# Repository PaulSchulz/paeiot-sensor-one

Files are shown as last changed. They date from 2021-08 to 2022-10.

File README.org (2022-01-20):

* paeiot-sensor-one :TOC:
  - [[#introduction][Introduction]]
  - [[#aim][Aim]]
  - [[#whats-in-this-repository][What's in this Repository]]
  - [[#usage-license][Usage License]]

** Introduction
PAE IoT LoRaWAN Sensor Module

This project is a product of the [[https://github.com/PaulSchulz/paeiot-experimenters][Port Adelaide Enfield Libraries IoT Experimenters]]
group.

The latest details for this project can be found in the regular [[blog/index.org][status updates]].
Comments are most welcome. See the above link for the group details.

#+CAPTION: Sensor One in a 3D Printed Indoor Enclosure
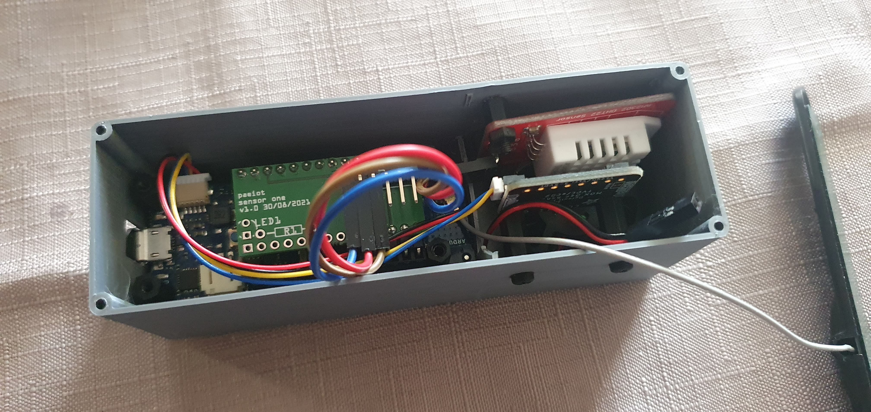
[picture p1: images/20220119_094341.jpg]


#+CAPTION: Outdoors Temperature and Humidity Sensor
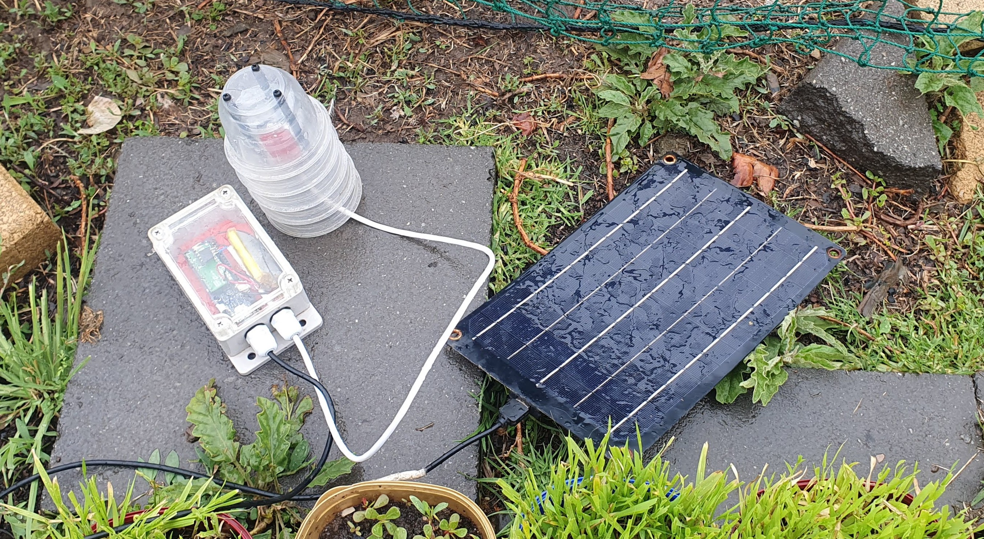
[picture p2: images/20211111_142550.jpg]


#+CAPTION: Data from Sensor One Outdoors Temperature and Humidity Sensor
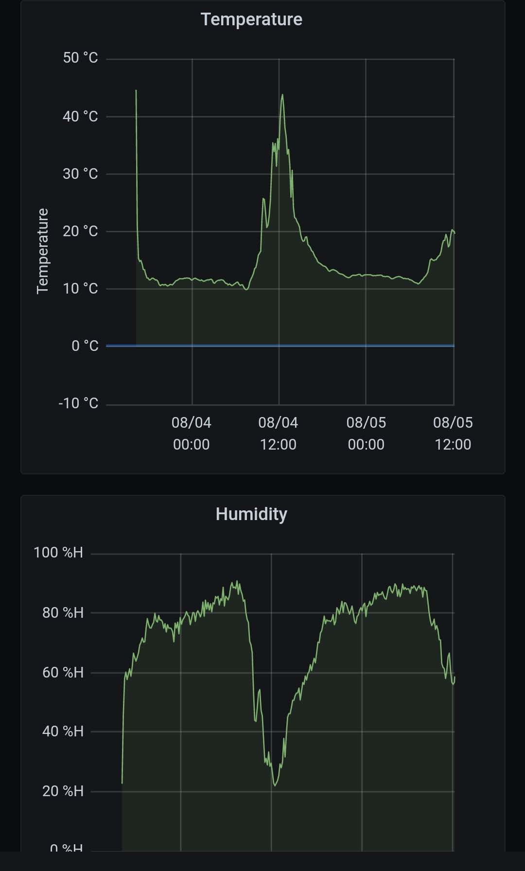
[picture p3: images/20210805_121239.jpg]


** Aim
Design and Build IoT LoRaWAN capable device which can be used for
environmental sensing.

The initial discussion paper (RFC) can be found here: [[https://github.com/PaulSchulz/paeiot-experimenters/blob/main/doc/rfc/00001-iot-lorawan-device.org][00001-iot-lorawan-device.org]]

The current project is based around the [[https://store.arduino.cc/usa/mkr-wan-1310][Arduino MRKWAN1310 board]], which uses a
SAND21 processor capable of low power operation, and a LoRa radio which allows
data logging via the LoRaWAN network.

** What's in this Repository
Subdirectories:
- [[Arduino/][Arduino]] - Directory containing Arduino sketches used by the project.
- [[doc/index.org][doc]] - Design and development documentation
- [[blog/index.org][blog]] - Progress Reports and Updates
- [[images/][images]]- Pictures, diagrams etc.
- [[stl/][stl]] - Sources for 3D printed parts
- [[fritzing/][fritzing]] - Sources for the Wiring Diagram, Printed Circuit Board (PCB) layout
  and production details, using the Friting application (old).
- [[kicad/][KiCAD]] - Sources for Wiring Diagram, Printed Circuit Board (PCB) layout
  and production details, using the KiCAD.

** Usage License

Unless mentioned elseware and where appropriate, all sources are made available
under a Free and Open Source License (GPLv3) for use for any purpose provided
that all derived works are made available under a Free and Open Source License.

See [[LICENSE]] for details.

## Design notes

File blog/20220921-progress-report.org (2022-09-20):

[[../README.org][Top]] | [[index.org][Index]]
-----

Microclimates - From the Coast to the Foothills (September Progress Report)

* Introduction

The Microclimates (Citizen Science) Project is flying ahead. Three sensors have
now been installed; located at the Port Adelaide Enfield Libraries at
Greenacres, Enfield and Port Adelaide. Two more sites are planned.

One big change with the firmware was required but otherwise, the sensors have
been deployed as designed.

The location has also been added to the data that is being collected, and the
graphs have been simplified and modified to allow additional sensors to
be automatically available.

A map has also been added which automatically shows the location of the
collected data.

[[https://grafana.iotdemo.dsp.id.au/d/ZxgEXUkVk/sensors-location-map?orgId=1&refresh=1m][Sensor Map]]

* Installation

** Greenacres (greenacres, mc-8)

This was the first site to be deployed and was reasonably straight forward.

It has been found that the sensor needs a LoRaWAN Gateway nearby to initially
connect to the network correctly. It is suspected that this is due to the
initial encryption handshake requires the sensor to also get a signal back from
a gateway. Once this has been done though, the sensor will happily transmit, and
gateways are able to pick up the signal without additional problems.

This issue also affects the sensor used for coverage mapping when starting up.
This can be addressed is a change to the firmware, where the LoRaWAN connection
can be tried again if it fails, after a timeout period.

** Enfield (enfield, mc-5)

The Enfield Libray sensor is located with the "Bee Hotel" and uses power from
the solar and battery system installed here. This means that the sensor is not reporting
it's solar and power levels (voltages) as the other sites are doing.

** Port Adelaide (port, mc-7)

Installation at this site required some 'finesse' in order to attach the sensor
to the outside of the library entrance, but it started recording data on Monday,
19 September ("port"", with sensor "mc-7").

** Next Sites (semaphore, park)

Work in ongoing to install sensors at Semaphore and The Parks Libraries

* Changes to the Firmware - Lowering Power Usage

Problems were found with excessive power usage on the processor. The delay
between measurements was beeing imposed by a 'busy sleep loop', which just kept
the processor running while waiting for the time for the next measurement.

This has ment that the sensor would use up all the battery power overnight, a
particular problem if the weather was overcast for a couple of days.

The solution was to use the low power sleep mode availble in the 'Sleepy Dog'
Arduino library. This reduced the power usage by a significant amount, to the
point where the power problem has essentially been solved. Measurements on
another sensor are ongoing to measure these results.

* Data Collection and Reporting

Updates have been made to the NodeRed data processing which now adds the
location (both site name and latitude and longitude)  to the data as it is collected. 

There are a couple of quick benefits from this. Site data can be consistently
displayed, even if a particular sensor fails and needs to be swapped out. Also,
the collected data can be displayed on a map with details about the site and
sensor at that location.

* Results

Grafana Graphs: [[https://grafana.iotdemo.dsp.id.au/d/BVf31-GVk/locations-all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][Dashboard]]

The initial data collected has already shown some interesting features, trends
and differences:
- The temperature and humidity data for each site generally track each other
  quite closely, generally within a degree or so, and 2% respectfully.
- There are still some interesting variabilities between the sensors, which are
  begging an explanation.
- It appears to be possible to detect the movement of a weather front through
  the Port Adelaide Enfield area by the delay in the temperature graphs.

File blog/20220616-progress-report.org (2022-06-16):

[[../README.org][Top]] | [[index.org][Index]]
-----

* Microclimates - From the Coast to the Foothills



Experimental setup of solar powered climate sensor stack. From the top - USB
solar panel; air temperature and humidity sensor in weather shield;
weather-proof box containing microprocessor board with LoRaWAN radio and
antenna.

** Progress Report - Thursday, 16 June 2022

Welcome to this (somewhat infrequent) update for the Sensor One IoT
project.

We have some big news.

Robert has been successful in obtaining a grant from National Science Week 2022
SA Community Grant for a microclimate measuring project in Port Adelaide Enfield
council - *From the coast to the foothills*

The sensors for the project will make use of the PAE IoT Experimenter's Group
Sensor One. While this is exciting, what is even better news is that we want to
use this opportunity to make the kit, with emphasis on a complete outdoor
environmental sensor package. The time frame for this is limited (about 4 months
in total), so the IoT Experimenter group is looking for people who may be able
to help out in many different ways.

The initial project kickoff meeting is being held during our regular meetup,
this Sunday, 19th June 2022, at 3pm at the Greenacres Library.

Some of the additional hardware features that can be looked at, in no
particular order:
- Adding a magnetic reset switch + circuit, for external sensor reset;
- Power usage measurement, and enabling microprocessor sleep modes;
- Add a watchdog circuit and automatic reset;
- Add power monitoring circuit (battery and power in); and
- Creating a version 2 of sensor circuit board.

Other useful activities:
- Robustness testing of sensors;
- Data modeling and analysis;
- Review of our IoT stack - The Things Network, NodeRED, InfluxDB and Grafana;
- NodeRED Flow Implementation;
- Grafana Dashboard Design;
- Documentation of hardware (bill of materials and build instructions), and
  project (blog and progress reports), including photography; and
- Design and preparation of 3D printed parts (if any).

*** More Information
- The project: https://stemlibrary.space/microclimates/
- An overview of the IoT: https://stemlibrary.space/iot-microclimate/
- An overview of the sensors we will be developing and deploying:
  https://stemlibrary.space/microclimate-sensor/

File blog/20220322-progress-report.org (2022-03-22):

[[../README.org][Top]] | [[index.org][Index]]
-----
* Progress Report - Saturday, 30 September 2022                          :TOC:
- [[#introduction--summary][Introduction / Summary]]
- [[#progress][Progress]]
  - [[#comments-on-coding-with-arduino-ides][Comments on Coding with Arduino IDEs]]
  - [[#investigating-the-cjmcu-8128-sensor-board][Investigating the CJMCU-8128 Sensor Board]]
  - [[#programming][Programming]]

* Introduction / Summary

|--------------+-------------------+---------+------------------------------------------------|
| Device       | Location / Role   | Status  | Comment                                        |
|--------------+-------------------+---------+------------------------------------------------|
| sally        | super-chook-house | WORKING | Stopped working due to faulty battery          |
| sensor-one-1 | lab               | TESTING |                                                |
| sensor-one-2 | kitchen           | WORKING | Was used to diagnose issues with other sensors |
| sensor-one-3 | bees              | BROKEN  | Broken and requires maintenance                |
| sensor-one-4 | lab / tracker     | BROKEN  | Requires software update to improve operation  |
|--------------+-------------------+---------+------------------------------------------------|

A quick update for March. Almost all of the sensors stopped working in one way or
another during this last period.

* Progress 
** Comments on Coding with Arduino IDEs
The following comments relate to using the various Arduino IDE's on Ubuntu 21.10. 

*** Arduino IDE v2

I decided to give the new (beta) Arduino development environment a go. It was a
very frustration experienced. It promises a lot with a new look and feel and
better library management, but it fell down with the management of the USB
programming and serial interface.

It would regularly, and without any obvious cause, stop being able to access the
device. Auto detection appeared to work well, but it than would not correctly
connect, or be able to program again after the Arduino MKR board was reset.

*** Arduino Cloud IDE

The Arduino Cloud IDE (browser based) works very well. An agent program needs to
be downloaded and run to allow it to access the USB ports for programming and
serial monitoring.

The library management is even extensive as all available online libraries are
available directly from within the tool. 

Compiling is done in the cloud, and the result is then downloaded to the
attached Arduino device, which was detected automatically.

The biggest issue I found was that there is a limit on the amount of compile
time is available (200 sec per day) under the free account level. It didn't take
very long to hit this limit.

*** Arduino IDE v1

I downloaded and updated to the latest version of the original Arduino IDE, and
was pleasantly surprised at how well it still worked.

The separate serial monitor can be made as big as required, and works well. 

While it isn't Emacs, it was still the easiest way to develop software for the
Sensor-One project.

** Investigating the CJMCU-8128 Sensor Board

This board is an I2C sensor board which combines three sensor chips. 

There was some confusion when wiring up the board, which was originally
connected directly to the I2C socket on the MKR board, which provides 5V rather
then 3.3V. This may have damaged the sensors, and the MKR board did not actually
boot in this configuration.

Correctly connecting the sensor to the 3.3V supply allowed the sensor to be read correctly. 

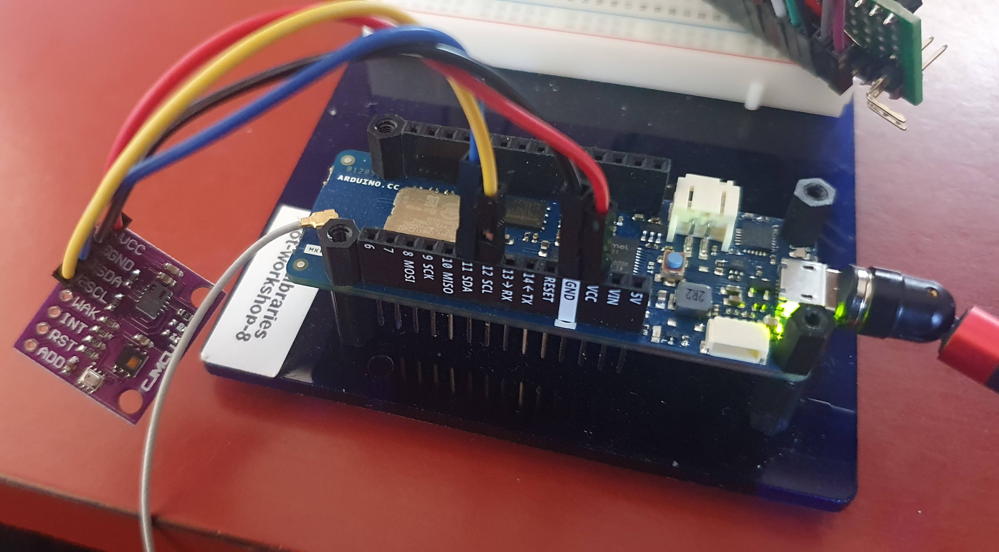
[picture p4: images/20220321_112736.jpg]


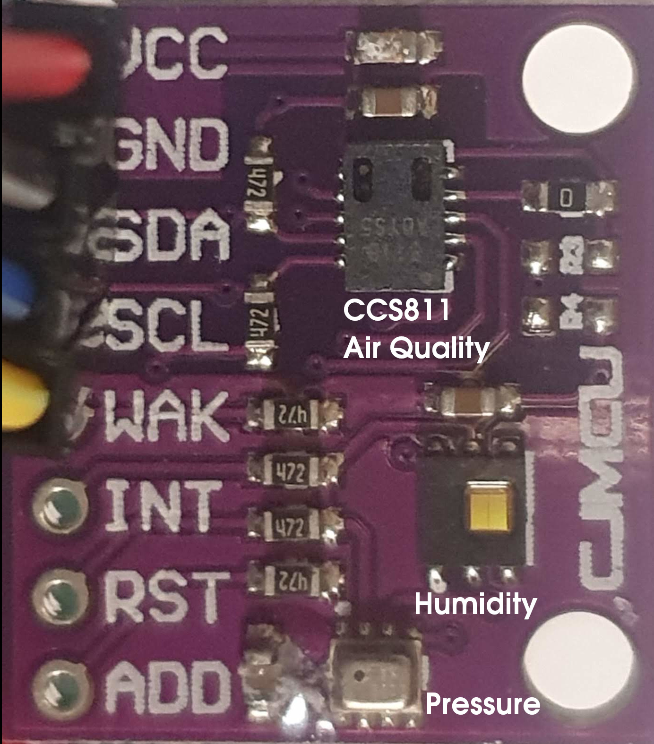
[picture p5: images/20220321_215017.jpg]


*** BME280 - Humidity sensor - Bosch
Datasheet: https://www.bosch-sensortec.com/products/environmental-sensors/humidity-sensors-bme280/

*** CCS811 - Air Quality Sensor - AMS
  Low Power Digital Gas Sensor. Datasheet: https://core-electronics.com.au/attachments/localcontent/CCS811_Datasheet-DS000459_65985a5bff8.pdf

*** HDC1080 - High Accuracy Humidity Sensor - Texas Instruments
Datasheet: https://www.ti.com/lit/ds/symlink/hdc1080.pdf

** Programming

Some more changes have been made to the 'Sensor One' code. Currently, the code
for the new sensors is still a work in progress, but several structural changes
have also been made.

The sensors connected to the MKR board can be chosen at compile time, and are
displayed when the software is run. This allows a working configuration (eg. for
the DHT sensors) to be put to the side while new code is developed.

#+begin_src 
# ----------------------------------------------------------------------------
# --- Sensor One                                                           ---
# --- Version: v1.3.0  21 Mar 2022                                         ---
# --- PAE IoT Experimenters                                                ---
# --- https://stemlibrary.space/iot-experimenters                          ---
# ----------------------------------------------------------------------------
# Features
#   LoRaWAN
#   CCS811
#   BME280
#   HDC1080
#   CayenneLPP
# ----------------------------------------------------------------------------
#+end_src

and is selected in the code with

#+begin_src 
// Features
#define LORAWAN            1
#define SENSOR_DHT         0
#define SENSOR_CCS811      1
#define SENSOR_BME280      1
#define SENSOR_HDC1080     1
#define FEATURE_CAYENNELPP 1
#+end_src

-----

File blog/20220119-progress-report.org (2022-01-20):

[[../README.org][Top]] | [[index.org][Index]]
-----
* Progress Report - Wednesday, 19 January 2022                            :TOC:
- [[#summary][Summary]]
- [[#update-details][Update Details]]

* Summary

This is a quick update, rather than a full progress report, on some recent work
on the Sensor One. This is because I am a little excited to show off what has
been recently done.

I was thinking about taking the sensor a little further and seeing how easily it
could be made into an indoor unit. 

There has been some announcements about delaying when Schools are going to start
again this year, because of COVID-19. A friend, who is a principal at a Primary
School in South Australia, ran a project last year using a CO2 sensor to monitor
air quality, so the students could tell when more fresh air and ventilation was
required. Their project has been [[https://www.facebook.com/LobethalLutheranSchool/videos/296081939214976][featured on the ABC]] and a video of their
work is available here: [[https://youtu.be/g7XMByInVQ0][YouTube Video]].

The PAE IoT - Sensor One, Air Quality Sensor in able do the same things as the
Primary School's sensor as it uses the same sensor device. With the addition of
a Raspberry Pi Computer, connected to your network and running free and open
source software, you can also [[file:../images/sensor-one-2-20220111.png][see the data]] in real time using the LoRaWAN
radio network and The Things Stack.

* Update Details

Our initial design of an indoors enclosure separated out the sensors and added a
small fan for drawing air. There was also room for an internal battery (LiPo) as
well as a second USB battery, or charging cable.

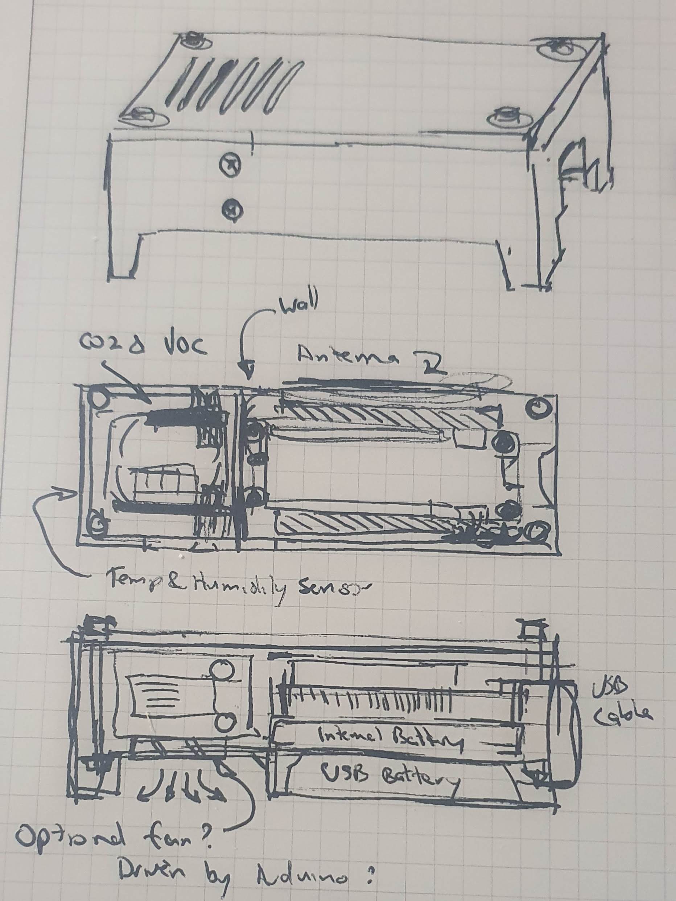
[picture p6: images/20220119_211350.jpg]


A 3D model was drawn up in [[https://www.tinkercad.com/][TinkerCAD]]...

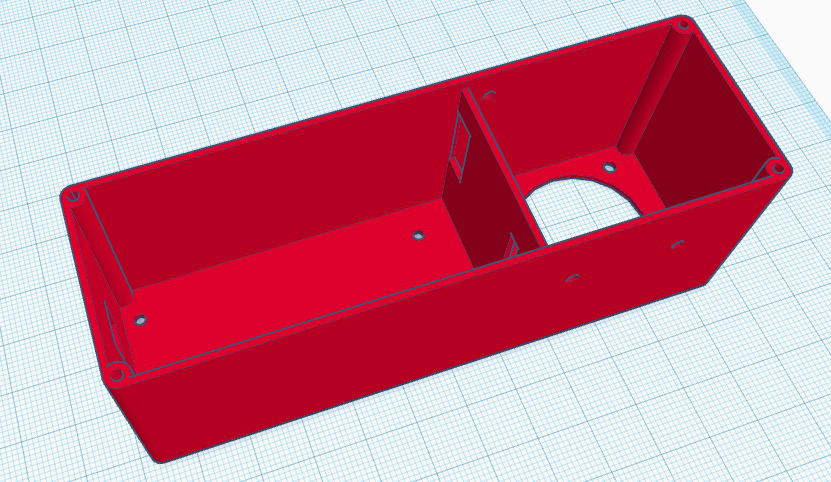
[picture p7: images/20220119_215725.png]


... printed.

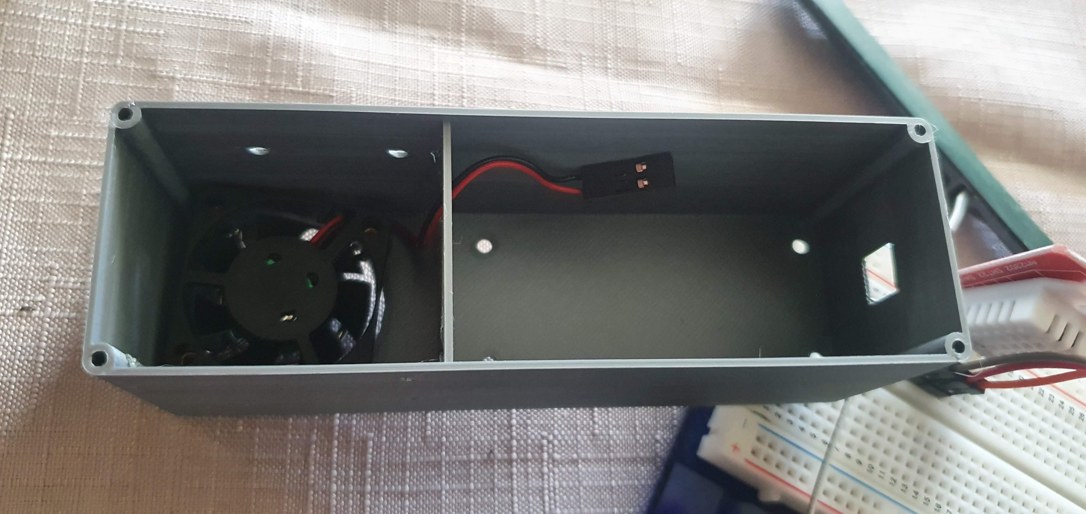
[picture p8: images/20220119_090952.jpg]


Then it was a /simple/ manner of putting all the electronics inside the enclosure.

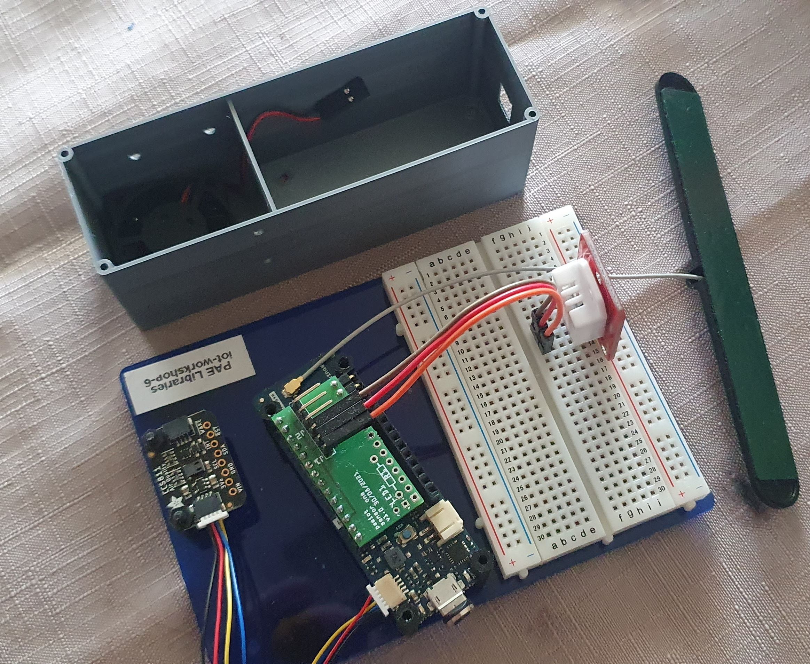
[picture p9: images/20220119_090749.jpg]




Mistakes were found, and noted for correcting in the next iteration.

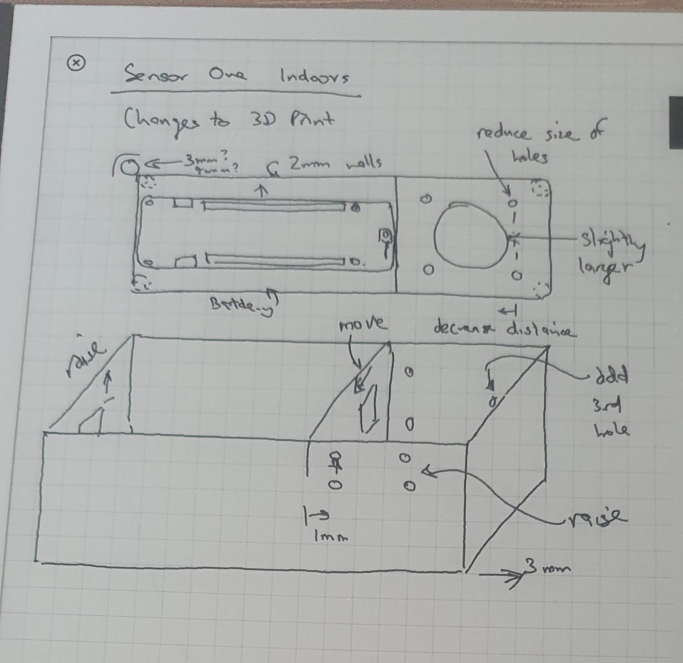
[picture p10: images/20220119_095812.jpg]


This unit is connected to power again (no battery yet), and is continuing to
report data, via The Things Network, NodeRED and InfluxDB to the Grafana
dashboard mentioned previously.

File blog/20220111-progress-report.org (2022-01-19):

[[../README.org][Top]] | [[index.org][Index]]
-----
* Progress Report - Saturday, 30 September 2022                          :TOC:
- [[#introduction--summary][Introduction / Summary]]
- [[#progress][Progress]]
  - [[#prototypes--deployed-devices][Prototypes & Deployed Devices]]
  - [[#hardware][Hardware]]
  - [[#outstanding-issues][Outstanding Issues]]
  - [[#what-to-do-next][What to do next]]
  - [[#what-else-to-do][What else to do...]]
  - [[#for-future-versions][For future versions]]

* Introduction / Summary

Welcome to the first progress report for 2022 and the seventh for the project.

Since the last report, one of the sensor units has been installed at the Enfield
Library, and is monitoring the temperature and humidity, both inside and out of
the new beehive.

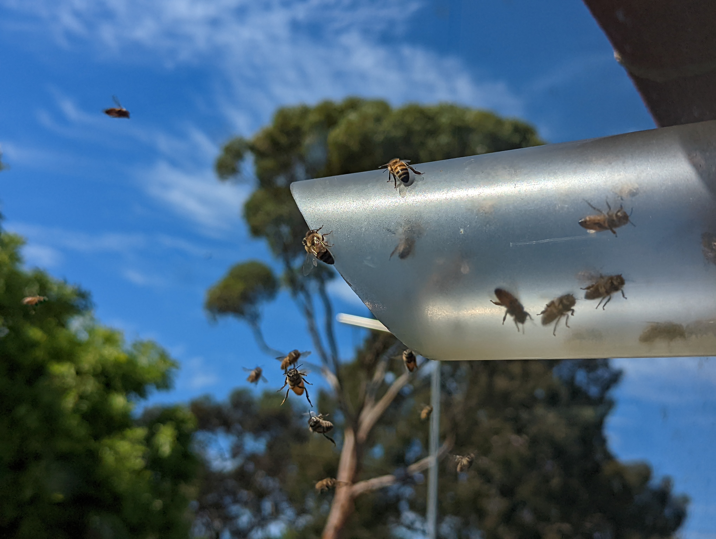
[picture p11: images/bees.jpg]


The Library has also installed a site outside for a native bee hotel, including
large solar panels. This means that the location is going to be able to have a
large array of environmental sensors added in due course.

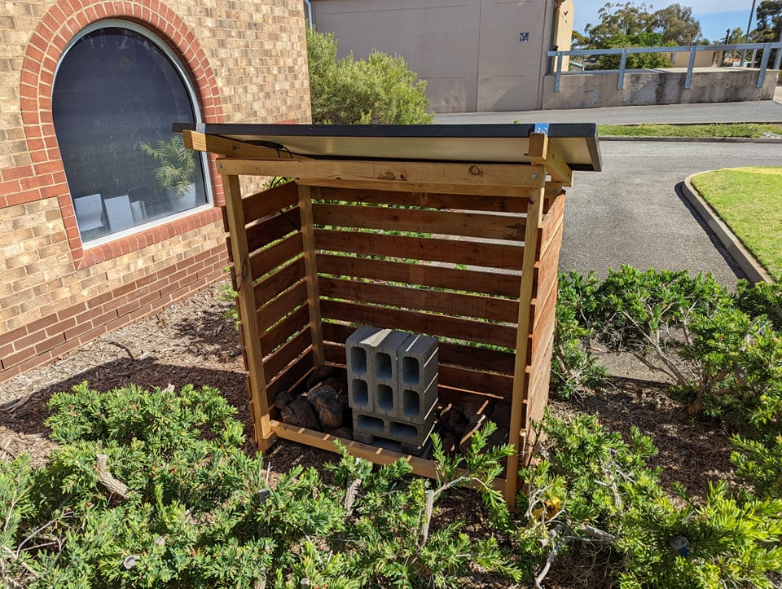
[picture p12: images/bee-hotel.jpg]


Some long overdue changes have also been made to the 'Sensor One' software.

The data packet format has been changed. Rather than sending a text based
message with the sensor readings, the software has been switched to use an
encoded format called [[https://docs.mydevices.com/docs/lorawan/cayenne-lpp][Cayenne Low Power Payload (Cayenne LPP)]]. This format uses
predefined measurement types, which allows both data tagging and reduced byte
count. This, in turn, allows more data to be sent in less time and will allow
measurements to be sent at a higher rate.

The 'Sensor One' hardware contains an I2C (eye-squared-sea) interface. This is a
data bus which allows a large number of additional sensors to be added, linked
together on a single set of cables. To the existing temperature and humidity
sensor, we have added a carbon dioxide (CO2) and volatile organic compound (VOC)
concentration sensor.

This data is being collected in a test setup currently sitting in a kitchen, and
it is possible to see the times when toast is being made and when the gas cooker
is in use.

At the system level, some work has also been done on scripting the process for
installing a standalone (personal) IoT server, based on a Raspberry Pi 4. This
would allow anyone to start collecting and displaying their sensor data quickly
and easily. 

The switch to using the Cayenne LPP packet format for data helps here as less
changes need to be made when additional sensors are added, or more sensing units
are deployed.

* Progress 
** Prototypes & Deployed Devices
*** Prototype 2 (sally) - Ongoing Testing

This prototype continues to collect temperature and humidity data in the garden.
The sensor has been raised up and attached to a stake so that it can catch any
breeze, as it still appears to be reading a higher temperature.

This sensor still uses the text based data protocol. The break in the data was
due to the power supply being interrupted by the chickens knocking over the
solar panel.

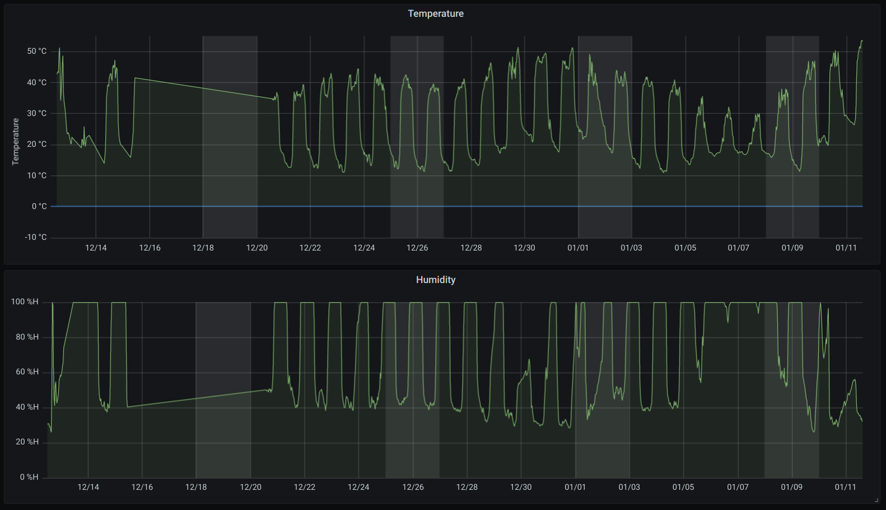
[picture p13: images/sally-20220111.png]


*** Library Bees (sensor-one-3) 

This sensor (as mentioned above) has been installed to monitor the interior and
exterior temperature and humidity of the beehive that has been put in the
Enfield Library.

This sensor is still using the old data protocol.

Due to location of the hive, there is no local power for network) access, so the
sensor is powered by the LiPo Battery and periodically recharged by attaching a
USB powerbank.

The break in the graph is when the sensor battery ran flat over the
Christmas/New Year break.

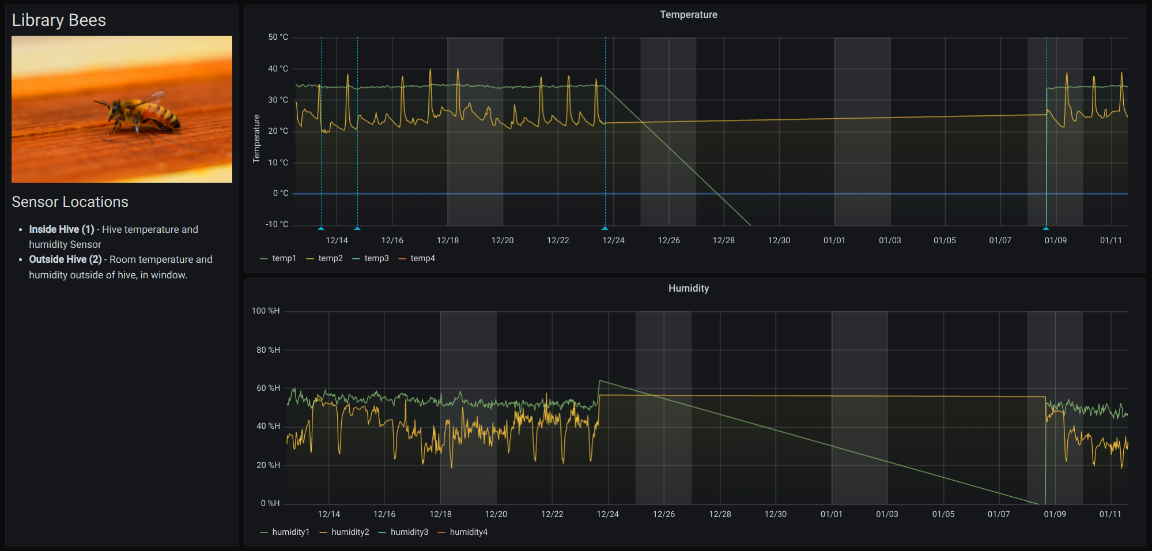
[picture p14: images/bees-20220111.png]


*** CO2 and VOC Concentrations (sensor-one-2) 

As mentioned in the introduction, changes have been made to the sensor software
to allow it to access I2C sensor hardware. as well as use the Cayenne LPP
format in the Cora WAN data packets.

Rather than decode the Cayenne LPP data in the The Things Network/Stack, there
is a module available for Node-RED which will do the same thing. Using this
allows more flexibility (eg. upgrades, deployment, backups) but the existing
Node-RED module does not implement all of the Cayenne LPP specification, in
particular the coding for 'concentration'.

Fortunately, it is a relatively straight forward process to download the source
code of the module, add the missing details and install the modified version as
a local version. For bonus points, the changes have been sent back upstream as a
'pull request' to the original [[https://github.com/ceugster/node-red-contrib-cayennelpp-extended][software on Github]]. "At this stage, the proposed
changes have yet to be merged.



** Hardware
*** KiCAD 

After some discussion with some more knowledgable members of the PAE IoT
Experimenters group, it was decided to move the PCB design from Fritzing to
KiCAD. (The Fritzing file will not be removed and will still be made available.)

Some assistance was required to get started with KiCAD, but once a set of
sensible default settings had been configured, it was quite fast to use, as it
makes extensive use of keystrokes to switch between features and drawing modes. 

Having a cheat sheet handy though, listing all of the keyboard shortcuts, would
be a very useful thing to have. The circuit schematic and PCB layout files can
be found in the [[file://../kicad/paeiot-sensor-one][kicad/paeiot-sensor-one]] sub directory. (The schematic of the board
we are creating can be found [[file:../kicad/paeiot-sensor-one/schematic.pdf][here]].)

*** Coding

**** Cayenne LPP Data Format

Details of the Cayenne LPP format can be found here [[https://docs.mydevices.com/docs/lorawan/cayenne-lpp][Cayenne Low Power Payload
(Cayenne LPP)]].

A module for NodeRED can be found here -   [[https://github.com/ceugster/node-red-contrib-cayennelpp-extended]]
which is a fork of another module.



*** Construction

(No changes)

** Outstanding Issues
*** Node-RED

Changes made to support 'contration sensor' need to be accepted by upstream.

*** Arduino 

Carried from last report, correspondence needs to be sent to Arduino, or an
issue submitted, regarding the new version of the MKRWAN1310 firmware (1.3.0),
given that it doesn't work.

This should be tested again.

*** The Things Network

Carried from last report. It is an issue that when configuring a device in The
Things Network, the AU915 Band Plan option B (Regional Parameters version: PHY
V1.0.2 REV B) still needs to be set separately, and Option A is the default
option.

This is still the case.

** What to do next
*** Connect more I2C sensor types
- Radiation sensor (geiger tube)
- Particulate sensor - not I2C, but serial based.

*** TODO Produce a new version of circit board
Circuit board (hat) need to be redesigned with the following features:
- Add headers for 4 sensor channels
- Add header for 5V supply, instead of power from USB
- Add buck converter option (maybe)
- Add power and battery voltage sensing circuit (maybe)

*** TODO Arduino Code
**** Add status LED.
Add additional status messaging
  - Flash status when starting up.
  - Flash Status when connecting/connected to LoRaWAN
**** Modify to use Arduino Low Power library and confirm power savings.

*** TODO Baseplate
- Rework battery slot.
- Look for space for option of Buck Converter board (power supply). 
  
** What else to do...
*** Create Bill of Materials (BOM)
- Include pricing and suppliers.
*** Create Installation Instructions
- How to download and use the code from this repository.
- How to connect up the sensors, battery, solar panel
*** Power budget calculations
- We need to work out how much power is being drawn from battery, and how much
  power we can get from solar panel.
- For how many 'cloudy' days can we remain powered and operating?
*** Radio Budget
- How long is the LoRa radio transmitting?
*** Investigate more sensors
eg. Wind speed and direction - https://hackaday.com/2022/01/11/3d-printed-sensor-for-finding-wind-direction-and-likely-much-more/

** For future versions
(Details will be included here as they are raised.)

-----

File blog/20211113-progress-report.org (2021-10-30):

[[../README.org][Top]] | [[index.org][Index]]
-----
* Progress Report - Saturday, 30 September 2021                  :TOC:
  - [[#introduction][Introduction]]
  - [[#contents][Contents]]
  - [[#progress][Progress]]
  - [[#outstanding-issues][Outstanding Issues]]
  - [[#what-to-do-next][What to do next]]
  - [[#what-else-to-do][What else to do...]]
  - [[#for-future-versions][For future versions]]

** Introduction
This is the sixth progress report for the "PAEIoT Sensor One" project. Delivery
of two partially assembled sensors has been made to the Port Adelaide Library
IoT Project has been made.

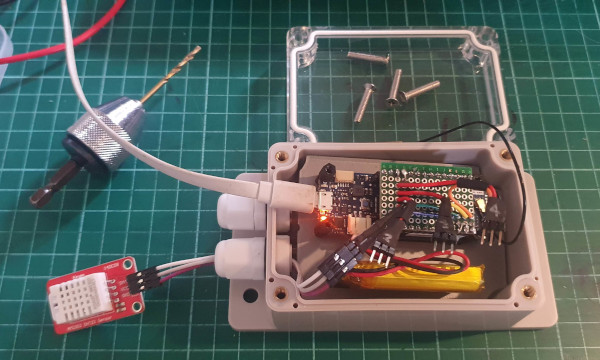
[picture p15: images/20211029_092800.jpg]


These sensors have each been programmed two collect 4 channels of temperature
and humidity data every 10 minutes.

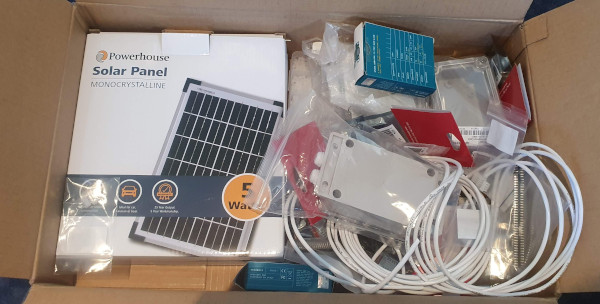
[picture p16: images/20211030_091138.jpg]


A box of a additional parts has been received for the Library project which will
be built into more sensors.
 
** Contents
  - [[#introduction][Introduction]]
  - [[#progress][Progress]]
  - [[#outstanding-issues][Outstanding Issues]]
  - [[#what-we-still-need-to-do-next][What (we still need to do) next]]
  - [[#what-else-to-do][What else to do...]]
  - [[#for-future-versions][For future versions]]

** Progress
*** Prototyping
|-------------+-------------------------------------------------+---------|
| Prototype 1 | Removed from service. Being used for mechanical |         |
|             | fit testing during sensor construction.         |         |
|-------------+-------------------------------------------------+---------|
| Prototype 2 | Being costructed with PCB v1.0                  | ONGOING |
|             | Using enclosure with internal micro antenna     |         |
|-------------+-------------------------------------------------+---------|

*** Devices for Testing and Evaluation
|--------------+-----------------------------------------------------+---------|
| sensor-one-3 | Delivered in enclosure to PAE Library               |         |
|              | with Sensor One v1.2 (4 channel)                    |         |
|--------------+-----------------------------------------------------+---------|
| sensor-one-4 | Delivered to PAE Library                            |         |
|              | with Sensor One v1.2 (4 channel)                    |         |
|--------------+-----------------------------------------------------+---------|
| sensor-one-3 | Received for testing, programming and sensor build. |         |
|--------------+-----------------------------------------------------+---------|
| sensor-one-3 | Received for testing, programming and sensor build. |         |
|--------------+-----------------------------------------------------+---------|

*** Fritzing
No work done on Fritzing Prototypes or Documentation
- Circuit Diagram
- PCB Layout
- PCB Production

*** Coding
**** The Things Network
A lot of time was spent trying to make the MKRWAN1310 work with the available
Arduino Library (MKRWAN) and The Things Network (version 3). There have been a
lot of subtle and not so subtle changes in both these projects, which has broken
then end to end communication channel.

A new template for the MKRWAN1310 in the Australian region (using AU915) was
submitted to The Things Network, which aims to make it very simple to add this
device for Australian users. This was accepted and now appears in the list of
options available:

|------------------+----------------------|
| Brand            | Arduino SA           |
| Model            | Arduino MKR WAN 1310 |
| Hardware Ver.    | 1.0                  |
| Firmware Ver.    | 1.2.3                |
| Profile (Region) | AU_915_928           |
|------------------+----------------------|

When using the profile (see image) then Regional Frequency settings stillyy needs
to be tweeked after the device has been configured to choose 'Option B'.

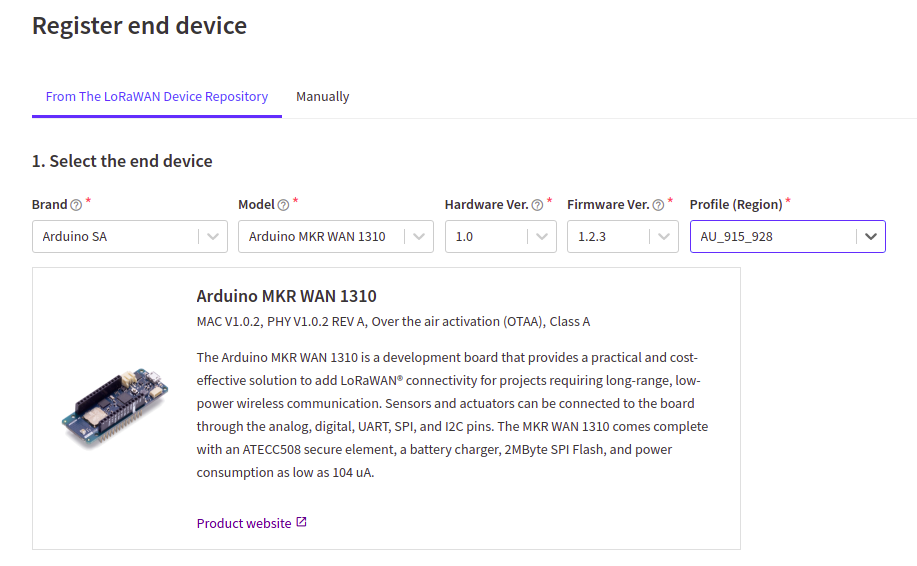
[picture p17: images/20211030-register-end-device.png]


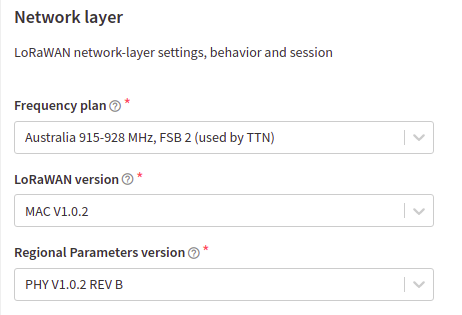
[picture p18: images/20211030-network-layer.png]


**** Arduino WAN Firmware
The firmware that comes with the MLRWAN1310 is version 1.2.0 and needs to be
upgraded. A new version of the firmware (currently 1.3.0.0) is available via the
Web Editor, but it didn't work (unsure why at this stage).

The previous known working version 1.2.0 is being install via the desktop
Arduino editor, using MKRWAN library version 1.1.0.

**** Arduino Code
The Arduino code has had a lot of changes, with a new version "Sensor One v1.2 28
Oct 20211020"
- 4 Data channels are collected and transmitted via LoRaWAN (text format)
- Status LED turned on during transmission / reception window
- Simplified serial output
- Additional processing of null measurments
- Reading period set to 10 minutes

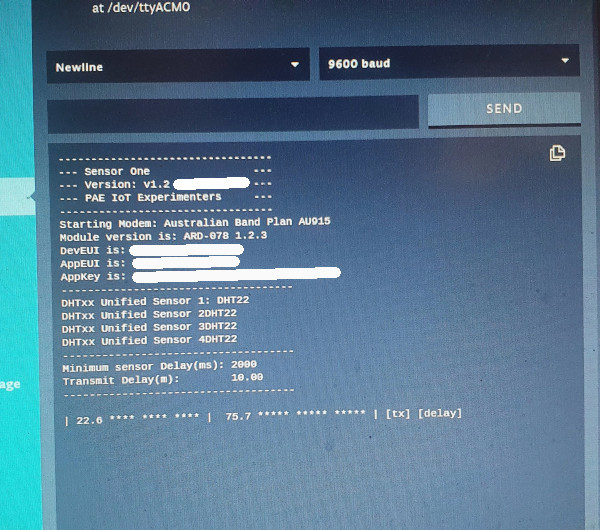
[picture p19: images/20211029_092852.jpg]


**** MKRWAN1310 Firmware
When working with the MKRWAN1310, the example Arduino sketches provided with the
MKRWAN library encourage that the MKRWAN1310 be upgraded to the latest firmware.
As of this moment, the version 1.3.0.0 of the firmware is available, but it
is broken for some reason.

*** Construction
**** Baseplate reworked
The slot in the baseplate was made larger to accommodate a larger battery (10 mm
rather than 7mm).

This slot and possibly design needs to be changed as the battery fit is
interfered with by lugs underneath from the enclosure. Battery should maybe be
moved closer to the MKRWAN1310 board.

Two baseplate versions available for battery sizes - 7mm and 10mm
- paeiot-sensor-one-baseplate-7.stl
- paeiot-sensor-one-baseplate-10.stl

** Outstanding Issues
*** Arduino 
Correspondence needs to be sent to Arduino, or an issue submitted,
regarding the new version of the MKRWAN1310 firmware (1.3.0), given that it
doesn't work. 

*** The Things Network
It is an issue that when configuring a device in The Things Network, the AU915
Band Plan option B (Regional Parameters version: PHY V1.0.2 REV B) still needs
to be set separately, and Option A is the default option.

** What to do next
*** TODO Bring up two new boards and built sensors
- sensor-one-1
- sensor-one-2

*** TODO Produce a new version of circit board
Circuit board (hat) need to be redesigned with the following features:
- Add headers for 4 sensor channels
- Add header for 5V supply, instead of power from USB
- Add buck converter option (maybe)
- Add power and battery voltage sensing circuit (maybe)

*** TODO Arduino Code
**** Add status LED.
Add additional status messaging
  - Flash status when starting up.
  - Flash Status when connecting/connected to LoRaWAN
**** Modify to use Arduino Low Power library and confirm power savings.

*** TODO Baseplate
- Rework battery slot.
- Look for space for option of Buck Converter board (power supply). 
  
** What else to do...
*** Create Bill of Materials (BOM)
- Include pricing and suppliers.
*** Create Installation Instructions
- How to download and use the code from this repository.
- How to connect up the sensors, battery, solar panel
*** Power budget calculations
- We need to work out how much power is being drawn from battery, and how much
  power we can get from solar panel.
- For how many 'cloudy' days can we remain powered and operating?
*** Radio Budget
- How long is the LoRa radio transmitting?

** For future versions
(Details will be included here as they are raised.)

-----

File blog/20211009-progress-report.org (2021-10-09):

[[../README.org][Top]] | [[index.org][Index]]
-----
* Progress Report - Saturday, 28 August 2021                              :TOC:
  - [[#introduction][Introduction]]
  - [[#progress][Progress]]
  - [[#outstanding-issues][Outstanding Issues]]
  - [[#what-to-do-next][What to do next]]
  - [[#what-else-to-do][What else to do]]

** Introduction
This is the fifth progress report for the "PAEIoT Sensor One" project.
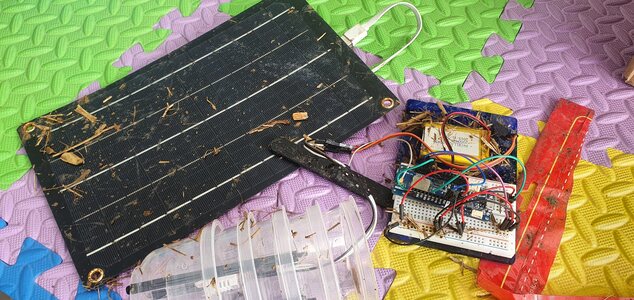
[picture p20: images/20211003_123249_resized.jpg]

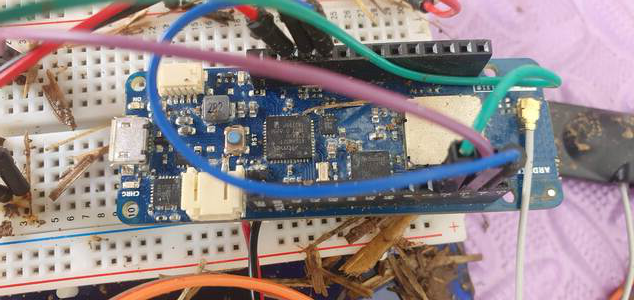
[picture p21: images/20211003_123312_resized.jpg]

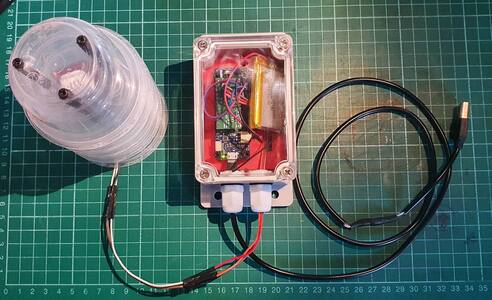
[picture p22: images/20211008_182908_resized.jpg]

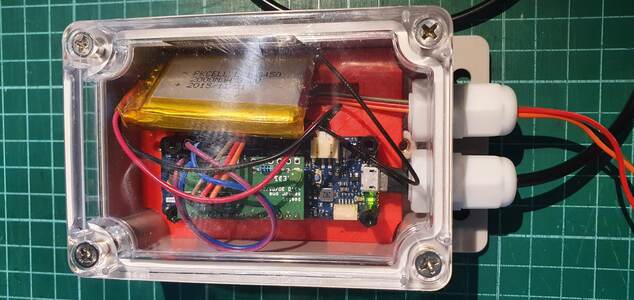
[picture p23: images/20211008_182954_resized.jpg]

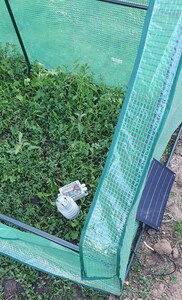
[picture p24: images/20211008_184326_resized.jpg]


** Progress
*** Events
During the last week, strong overnight winds blew over the greenhouse enclosure
containing Prototype 1 unit and caused the circuit board to get exposed to rain
and suffer water damage. Attempts for minimise the damage caused by corrosion
(soaking in isopropyl-alcohol and allowing to thoroughly dry out) did not
restore full functionality to the board. 

When powering on and monitoring via the serial port, the processor appears to be
working OK, but not the LoRa radio, which fail to respond during the radio
initialisation, which subsequently times out.

It is suspected that there is water damage, corrosion, or moisture under the
radio module shielding. This is an area which can not be readily inspected.

As a result, to continue testing, the second prototype board was functionally
completed and installed in its place. Prototype 2 (sally) uses the PCB v1.0 with
modifications, in the weather proof enclosure, with same battery, solar panel
and sensor as Prototype 1 (laura), as well as the addition of the internal micro
antenna.

*** Prototyping
**** DONE Prototype 1 (laura)
CLOSED: [2021-10-09 Sat 20:54]

Ongoing testing has ceased due to damage. Module Firmware: ARD-078 1.2.0 

**** ONGOING Prototype 2 (sally)
Prototype completed and installed for testing.
- Uses PCB v1.0 with modifications.
- Uses new internal micro antenna.
- Uses new board configuration process.
- Upgraded LoRa radio firmware: ARD-078 1.2.3
- Configured TTNv3 to accept data.
- Configured Grafana to plot data.
- Installed in testing location. 

*** Fritzing
**** ONGOING Layout
PCB updated to v1.1 with correct template.

*** Coding
**** DONE Debugging
CLOSED: [2021-10-09 Sat 21:05]
- Issue found with initial Serial initialisaiton

*** MKRWAN1310 Testing, Installation and Bring-up Process
- Use Arduino IDE with Device support and MKRWAN libraries. The web based IDE
  will have the most up to date version of the official libraries.
- Upgrade LoRa Firmware: From examples install sketch 'MKRWANFWUpdate_standalone'
- From examples, install 'FirstConfiguration' - change band plan from EU to AU915
  Add to sketch: modem.sendMask("ff000000f000ffff00020000");

** Outstanding Issues
*** CANCELLED Upgrade LAN Library
CLOSED: [2021-10-09 Sat 21:08]
Upgrading the radio module firmware (and removing the wait for the serial
connection) has allowed the sensor to now reliably connect to the LoRaWAN
network without any other issues.

*** CANCELLED Order new version o circit board
CLOSED: [2021-10-09 Sat 14:34]
Ordering new circuit boards now appears to include a 20 euro shipping fee which
wasn't included in the first batch. Need to investgate this before doing another
order or v1.1. May skip top v1.2 with additional functionality.

** What to do next
*** TODO Code
**** Add status LED
- Flash status when starting up.
- Flash Status when connecting/connected to LoRaWAN
- Flash status LED when transmitting.
**** Modify to use low power settings and confirm power usage
- Add the Arduino Low Power library
*** TODO Create Bill of Materials (BOM)
- Include pricing and suppliers.  
*** TODO Rework PCB
- Expand number of sensor channels to 4
- Add option for 5V power-in with Buck Converter, instead of USB.
*** TODO Rework Base plate design
- Expand battery slot to hold 
  
** What else to do
*** Investigate additional waterproofing
- Conformal coating / potting for MKRWAN1310.
- Water proofing cabling into/out-of enclosure.
*** Create Installation Instructions
- How to test and install, upgrade sotware on MKRWAN1310.
- How to download and use the code from this repository.
- How to connect up the sensors, battery, solar panel
*** Power budget calculations
- We need to work out how much power is being drawn from battery, and how much
  power we can get from solar panel.
- For how many 'cloudy' days can we remain powered and operating?
*** Radio Budget
- How long is the LoRa radio transmitting?

-----

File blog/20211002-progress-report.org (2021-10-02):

[[../README.org][Top]] | [[index.org][Index]]
-----
* Progress Report - Saturday, 28 August 2021                              :TOC:
  - [[#introduction][Introduction]]
  - [[#progress][Progress]]
  - [[#outstanding-issues][Outstanding Issues]]
  - [[#what-we-still-need-to-do-next][What (we still need to do) next]]
  - [[#what-else-to-do][What else to do...]]
  - [[#for-future-versions][For future versions]]

** Introduction
This is the fourth progress report for the "PAEIoT Sensor One" project. It has
been a while since that one has been written so I thought I might as well put
together a short update. (Sorry, no pictures).

** Progress
*** Prototyping
|-------------+---------------------------------------------+---------|
| Prototype 1 | Testing - On-going and good                 | ONGOING |
|             | Tempurature sensor enclosure added.         |         |
|-------------+---------------------------------------------+---------|
| Prototype 2 | Being costructed with PCB v1.0              | ONGOING |
|             | Using enclosure with internal micro antenna |         |
|-------------+---------------------------------------------+---------|
*** Fritzing
|-----------+--------------------------------------------+---------|
| Templates | New template found - MKRWAN1300            | DONE    |
|           | In correspondence with Arduino about       |         |
|           | correcting their version.                  |         |
|-----------+--------------------------------------------+---------|
| Circuit   | Diagram Completed                          | DONE    |
|-----------+--------------------------------------------+---------|
| Layout    | PCB updated to v1.1 with correct template. | ONGOING |
|-----------+--------------------------------------------+---------|
*** Coding
|-----------+------------------------------------------------+-------|
| Debugging | Issue found with initial Serial initialisaiton | FIXED |
|-----------+------------------------------------------------+-------|

** Outstanding Issues
*** TODO Upgrade Firmware on MRKLAN1301 and LAN Library
The existing MKRWAN1310 boards uses whatever the firmware was that came with the
board, and this needs to be updated. It has been suggested that the LoRaWAN connection issue is related to this.
*** TODO Order new version o circit board

** What (we still need to do) next
*** TODO Code
**** Add status LED.
  - Flash status when starting up.
  - Flash Status when connecting/connected to LoRaWAN
  - Flash status LED when transmitting.
**** Modify to use Arduino Low Power library and confirm power savings.
  
** What else to do...
*** Create Bill of Materials (BOM)
- Include pricing and suppliers.
*** Create Installation Instructions
- How to download and use the code from this repository.
- How to connect up the sensors, battery, solar panel
*** Power budget calculations
- We need to work out how much power is being drawn from battery, and how much
  power we can get from solar panel.
- For how many 'cloudy' days can we remain powered and operating?
*** Radio Budget
- How long is the LoRa radio transmitting?

** For future versions
*** Expand the number of sensor channels to 4. (Rework of PCB required.)

-----

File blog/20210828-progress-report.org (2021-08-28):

[[../README.org][Top]] | [[index.org][Index]]
-----
* Progress Report - Saturday, 28 August 2021                              :TOC:
  - [[#introduction][Introduction]]
  - [[#progress][Progress]]
  - [[#outstanding-issues][Outstanding Issues]]
  - [[#what-we-still-need-to-do-next][What (we still need to do) next]]
  - [[#what-else-to-do][What else to do...]]
  - [[#other-notes][Other Notes]]

** Introduction

This is the third progress report for the "PAEIoT Sensor One" project.
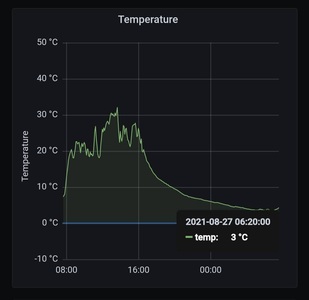
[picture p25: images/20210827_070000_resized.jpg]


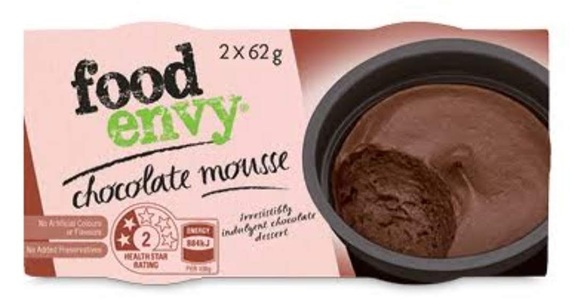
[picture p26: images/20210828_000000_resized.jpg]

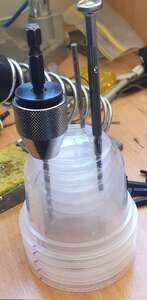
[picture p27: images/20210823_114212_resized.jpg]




** Progress
We have:
- Continued with ongoing testing of first prototype. It has continued to run
  well in wintery weather condition. Recorded Adelaide's coldest day of the year
  on Friday, 27 August
- 3D Printed better baseplate (2 copies) using the #d Printer at the PAE Library Maker Space at the Parks Library.
- Initial attempt with '[[https://fritzing.org/][Fritzing]]' to produce a printed circuit board as shield
  See file in 'fritzing' directory for sources.
- Build a weather shield enclosure for external sensor, using available plastic containers.

#+caption: Initial attempt at circuit board design with Fritzing.


** Outstanding Issues
*** Upgrade Firmware on MRKLAN1301 and LAN Library
The existing MKRWAN1310 boards uses whatever the firmware was that came with the
board, and this needs to be updated. It has been suggested that the LoRaWAN connection issue is related to this.

** What (we still need to do) next
- Extend cable on temperature sensor to support inside/outside measurements.
- Complete wiring diagram.
- Add status LED.
  - Flash status when starting up.
  - Flash Status when connecting/connected to LoRaWAN
  - Flash status LED when transmitting.
- Modify to use Arduino Low Power library and confirm power savings.

** What else to do...
*** Create Bill of Materials (BOM)
- Include pricing and suppliers.
*** Create Installation Instructions
- How to download and use the code from this repository.
- How to connect up the sensors, battery, solar panel
*** Power budget calculations
- We need to work out how much power is being drawn from battery, and how much
  power we can get from solar panel.
- For how many 'cloudy' days can we remain powered and operating?
*** Radio Budget
- How long is the LoRa radio transmitting?

-----
** Other Notes
*** Using Image Magick to rescale images
On my Ubuntu Laptop, images and photos for this blog have been re-scaled using the
'convert' tool from the Image Magick suite of tools

The following will produce a resized image with height 300px.
#+begin_src shell
  FILE=20210823_114212.jpg
  convert $FILE -resize x300 ${FILE%.jpg}_resized.jpg
#+end_src

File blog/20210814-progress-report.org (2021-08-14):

[[../README.org][Top]] | [[index.org][Index]]
-----
* Progress Report - Saturday, 15 August 2021                              :TOC:
  - [[#introduction][Introduction]]
  - [[#progress][Progress]]
  - [[#outstanding-issues][Outstanding Issues]]
  - [[#other-issues][Other Issues]]
  - [[#what-we-still-need-to-do-next][What (we still need to do) next]]
  - [[#what-else-to-do][What else to do...]]

** Introduction

Second progress report for the "PAEIoT Sensor One" project.



** Progress
We have:
- Continued with ongoing testing of first prototype. It has continued to run
  well in wintery weather condition.
- Had a conversation with *Arduino.CC* (thanks Robert) and amongst other things
  discussed the OTAA authentication issue.
- Received two waterproof boxes for mounting the sensor. These boxes from
  [[https://adafruit.com][Adefruit]] cost US$9.95 and include two cable glands.
- Designed and 3D Printed a baseplate for mounting the Arduino MKRWAN1310,
  battery and cable connections.
- Received a [[https://core-electronics.com.au/usb-power-meter-color-tft-lcd.html][USB Power Monitor]] and started looking at power usage of the sensor
  board. (The solar panel was producing 0.141A @ 5.25V for powering the board
  and recharging the battery.)
- Started investigating '[[https://fritzing.org/][Fritzing]]' to produce a wiring diagram. (See the
  fritzing directory.) Fritzing also allows easy creation of circuit board
  layouts, as well as easy ordering and production. It is possible to produce 6
  double sided boards to fit onto the MKRWAN1310 for 11.09€.

** Outstanding Issues
*** (In progress) Initial login and authentication with the LoRaWAN network
See above.

** Other Issues
*** The [[https://reprap.org/wiki/RepRapPro_Huxley][ReprapPro Huxley]] 3D printer being used is having reliability issues. It will print the first layer reliably, but then fail on the second or so. It proably needs the hot-end rebuilt. 

** What (we still need to do) next
- Extend cable on temperature sensor to support inside/outside measurements.
- Complete wiring diagram.
- Add status LED.
  - Flash status when starting up.
  - Flash Status when connecting/connected to LoRaWAN
  - Flash status LED when transmitting.
- Modify to use Arduino Low Power library and confirm power savings.

** What else to do...
*** Create Bill of Materials (BOM)
- Include pricing and suppliers.
*** Create Installation Instructions
- How to download and use the code from this repository.
- How to connect up the sensors, battery, solar panel
*** Power budget calculations
- We need to work out how much power is being drawn from battery, and how much
  power we can get from solar panel.
- For how many 'cloudy' days can we remain powered and operating?
*** Radio Budget
- How long is the LoRa radio transmitting?

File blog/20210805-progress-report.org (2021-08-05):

[[../README.org][Top]] | [[index.org][Index]]
-----
* Progress Report - Thursday, 5 August 2021                               :TOC:
  - [[#introduction][Introduction]]
  - [[#progress][Progress]]
  - [[#outstanding-issues][Outstanding Issues]]
  - [[#what-to-do-next][What to do next]]
  - [[#what-else-to-do][What else to do...]]

** Introduction

Welcome to the first progress report for the "PAEIoT Sensor One" project.





** Progress
We have:
- Connected the Arduino MKRWAN1510 board to two DHT22 (AM2302) Temperature and
  Humidity sensors;
- Run the example LoRaWAN on the MKRWAN1510 (from the LORAWAN Arduino Library);
- Modified and written an Arduino sketch which reads the Temperature and
  Humidity Sensors and transmits them to an MQTT application via The Things
  Stack, *every 2 minutes*;
- Modified exiting *NodeRED* configuration to interpret data and save into
  *InfluxDB* database, which is then plotted with *Grafana* dashboard. (These
  services were already existing resources.); and
- Tested prototype, with battery and solar power charging. It ran for several
  days, reliably collecting data.

Related:
- Investigated method for using git with 'ardunio_secrets.h' file without
  leaking credentials (git [ignore|unignore|ignored]).
  
** Outstanding Issues
***  Initial login and authentication with the LoRaWAN network
The LoRa radio does not authenticate with the LoRaWAN network reliably first
time (via OTAA). It will connect after several restarts/resets/power cycles.
Once connected, transmission and reception of data is 

** What to do next
- Investigate LoRaWAN authentication issue.
- Extend cable on temperature sensor to support inside/outside measurements.
- Investigate waterproof enclosure options.
- Document wiring (wiring diagram).
- Add status LED.
  - Flash status when starting up.
  - Flash Status when connecting/connected to LoRaWAN
  - Flash status LED when transmitting.
- Create Github repository for "Sensor One" project
- Modify to use Arduino Low Power library.

** What else to do...
*** Create Bill of Materials (BOM)
- Include pricing and suppliers.
*** Create Installation Instructions
- How to download and use the code from this repository.
- How to connect up the sensors, battery, solar panel
*** Power budget calculations
- We need to work out how much power is being drawn from battery, and how much power we can get from solar panel.
- For how many 'cloudy' days can we remain powered and operating?

*** Radio Budget
- How long is the LoRa radio transmitting?

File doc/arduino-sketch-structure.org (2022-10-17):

#+TITLE: Arduino Sketch Structure

* Introduction

The following describes the structure of the Arduino Sketch used in the sensor (paeiot-sensor-one.ino).

Arduino sketches have three main parts:
- Library declarations (via the #include statement);
- Setup function (setup()); and
- Main loop function (loop())

The sensor sketch separates out the various required capabilities from these
functions, which can be enabled or disabled by defining appropriate variables.

* Capabilities
The capabilities of the sketch are set with the following parameters defined at
the beginning of the script.

#+begin_src c
#define FEATURE_SERIAL TRUE
#define LORAWAN        TRUE
#define SENSOR_STATUS  TRUE
#define SENSOR_DHT     FALSE
#define SENSOR_CCS811  FALSE
#define SENSOR_BME280  FALSE
#define SENSOR_SCD30   TRUE

#define FEATURE_RTC           FALSE
#define FEATURE_WATCHDOG      TRUE
#define FEATURE_POWER_MONITOR TRUE
#+end_src

When starting up, the sketch will output what features and capabilities are enabled.

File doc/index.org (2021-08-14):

[[../README.org][TOP]]
-----
* Documentation                                                           :TOC:
  - [[#microprocessor-board][Microprocessor Board]]
  - [[#enclosure][Enclosure]]
  - [[#baseplate][Baseplate]]

** Microprocessor Board
MKRWAN1510

** Enclosure
- Suggested enclosure: Flanged Weatherproof Enclosure With PG-7 Cable Glands
- Link: https://www.adafruit.com/product/3931

** Baseplate
3D Printed - See STL file

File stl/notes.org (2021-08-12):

* stl files                                                               :TOC:
  - [[#introduction][Introduction]]
  - [[#paeiot-sensor-one-baseplate][paeiot-sensor-one-baseplate]]

** Introduction
The file here are the sources required for 3D printed pieces.

These parts have been created using [[https://www.tinkercad.com][TinkerCAD]], and exported in both OBJ as well
as STL file formats.

If required, the original designs can be made available for colabouration in
TinkerCAD. (At some stage the designs will be redone on a more open platform.)

** paeiot-sensor-one-baseplate
Baseplate design for mounting MKRWAN1310 board in enclosure.

Status: Work-in-progress

Size/Shape
- Thickness: 3mm
- Width: 85mm
- Height: 60mm
- Corner cut-outs: 10mm radius
- Battery Slot: 52mm x 7mm

- Mounting holes: 2x 4mm x 80mm centres

MKRWAN1310 Board
- Mounting Holes: 2.5mm
- Spacing width: 20.5mm
- Spacing length: 57mm

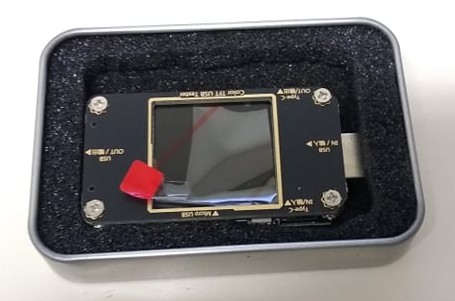
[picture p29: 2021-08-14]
images/233713997_159332209643053_2456921943083975539_n.jpg

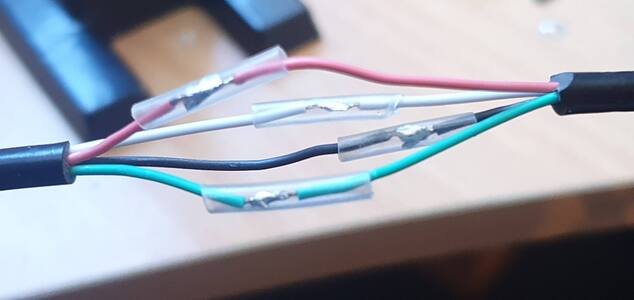
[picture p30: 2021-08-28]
images/20210823_105839_resized.jpg

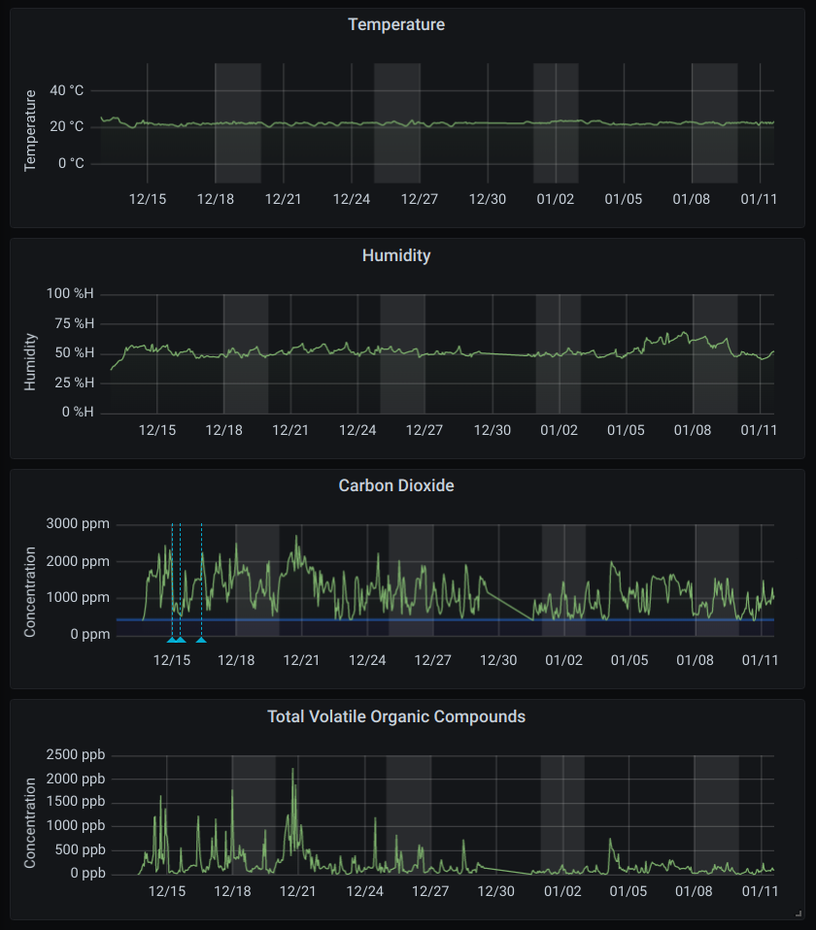
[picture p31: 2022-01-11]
images/sensor-one-2-20220111.png

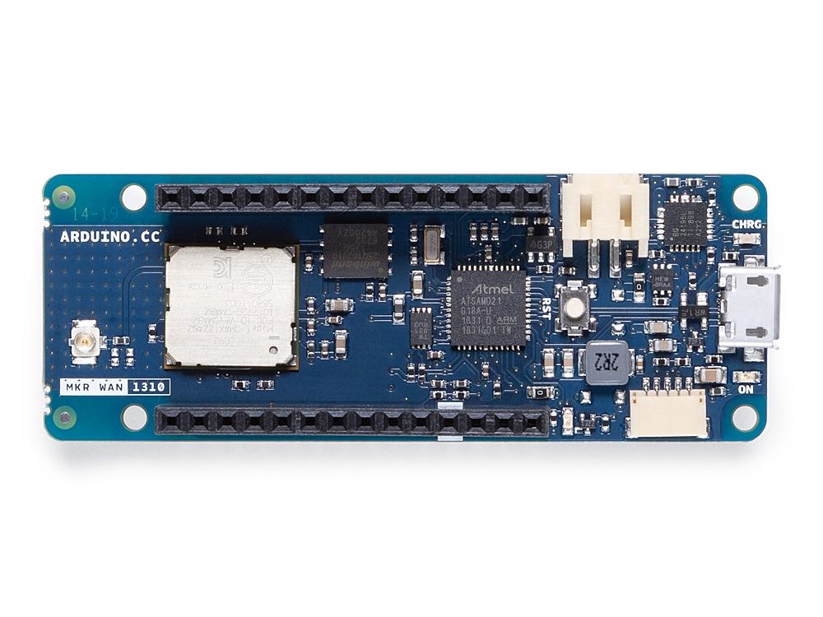
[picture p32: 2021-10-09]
images/MKRWAN1310-03.jpg

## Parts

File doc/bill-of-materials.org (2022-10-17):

#+TITLE: Bill of Materials

* Initial Sensor
| Item      | Description                    | Supplier | Number | Unit Cost | Total    |
|-----------+--------------------------------+----------+--------+-----------+----------|
| Enclosure | Flanged Weatherproof Enclosure | Adafruit |      1 | US$9.95   | US$9.95  |
|           | with PG-7 Cable Glands         |          |        |           |          |
|           | PartNo: 3931                   |          |        |           |          |
|           | SID: 3.10.2                    |          |        |           |          |
|-----------+--------------------------------+----------+--------+-----------+----------|
| Processor | Arduino MKRWAN1310             | Arduino  |      1 | US$30.40  | US$30.40 |
| + Radio   |                                |          |        |           |          |
|-----------+--------------------------------+----------+--------+-----------+----------|
| Sensors   | DHT22                          | Alibaba  |      2 | $2        | $4       |
|-----------+--------------------------------+----------+--------+-----------+----------|
| Sensor    | (Constructed)                  |          |        |           |          |
| Enclosure |                                |          |        |           |          |

* Deployed Sensor Package
In order also measure CO2 concentrations with the sensors, the *SDC30* sensor has
been used, which includes temperature and humidity sensors.

| Item      | Description                    | Supplier     | Num | Unit Cost | Total    |
|-----------+--------------------------------+--------------+-----+-----------+----------|
| Enclosure | Flanged Weatherproof Enclosure | Adafruit     |   1 | US$9.95   | US$9.95  |
|           | with PG-7 Cable Glands         |              |     |           |          |
|           | PartNo: 3931                   |              |     |           |          |
|           | SID: 3.10.2                    |              |     |           |          |
|-----------+--------------------------------+--------------+-----+-----------+----------|
| Processor | Arduino MKRWAN1310             | Arduino      |   1 | US$30.40  | US$30.40 |
| + Radio   |                                |              |     |           |          |
|-----------+--------------------------------+--------------+-----+-----------+----------|
| Sensor    | Seeed Studio SDC30 - I2C       | Seeed Studio |   1 | US$59.00  | US$59.99 |
|-----------+--------------------------------+--------------+-----+-----------+----------|
| Sensor    | (Constructed)                  |              |     |           |          |
| Enclosure |                                |              |     |           |          |

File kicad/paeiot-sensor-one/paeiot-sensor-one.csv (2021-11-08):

Reference | Value | Footprint | Datasheet
J2 | Conn | Connector_PinHeader_2.54mm:PinHeader_1x15_P2.54mm_Vertical | ~
J3 | Conn | Connector_PinHeader_2.54mm:PinHeader_1x15_P2.54mm_Vertical | ~
J7 | Conn_01x03_Male | Connector_PinHeader_2.54mm:PinHeader_1x03_P2.54mm_Horizontal | ~
J6 | Conn_01x03_Male | Connector_PinHeader_2.54mm:PinHeader_1x03_P2.54mm_Horizontal | ~
J1 | Power | Connector_PinHeader_2.54mm:PinHeader_1x02_P2.54mm_Horizontal | ~
R1 | R_Small | Resistor_THT:R_Axial_DIN0414_L11.9mm_D4.5mm_P15.24mm_Horizontal | ~
D1 | LED_Small | LED_THT:LED_D3.0mm | ~
J4 | Conn_01x03_Male | Connector_PinHeader_2.54mm:PinHeader_1x03_P2.54mm_Horizontal | ~
J5 | Conn_01x03_Male | Connector_PinHeader_2.54mm:PinHeader_1x03_P2.54mm_Horizontal | ~

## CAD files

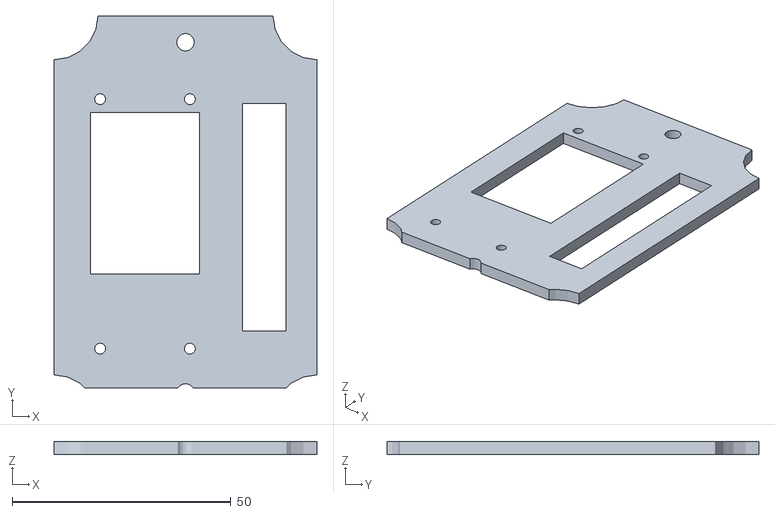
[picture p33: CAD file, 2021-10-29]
stl/paeiot-sensor-one-baseplate-10.stl
60.0 x 85.0 x 3.00

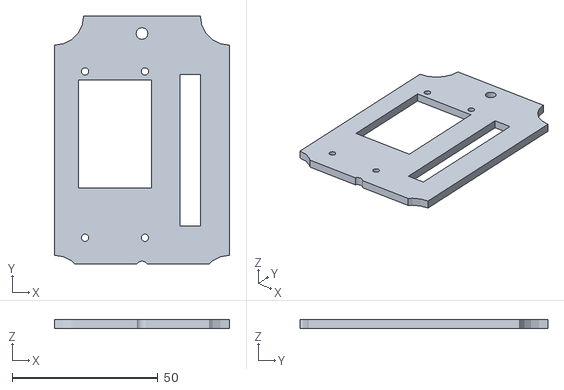
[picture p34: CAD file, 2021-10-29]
stl/paeiot-sensor-one-baseplate-7.stl
60.0 x 85.0 x 3.00

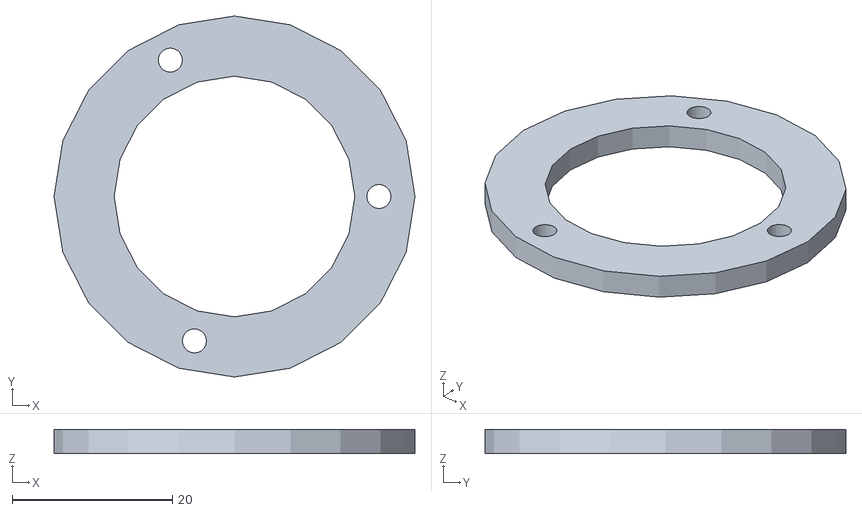
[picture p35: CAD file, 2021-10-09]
stl/paeiot-sensor-one-shield-base.stl
45.0 x 45.0 x 3.00

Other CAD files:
stl/paeiot-sensor-one-baseplate.stl

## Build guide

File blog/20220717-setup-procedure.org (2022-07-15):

[[../README.org][Top]] | [[index.org][Index]]
-----

Microclimates - From the Coast to the Foothills

* Introduction

The following are the procedure that is being used to setup and test the LoRaWAN
sensor hardware and ensure that they are working correctly with the LoRaWAN network.

It is planned setup all of the available sensor boards at the upcoming group
workshop on *Sun, 17 July 2022*. If device configuration details can be shared
(specifically the DevEUI), it should be possible to split the tasks across
several workstations/laptops.

These procedures don't include details of the final software as this is still
under development. The code can be found, in what ever state, in the 'src'
directory of this GitHub repository.

For all MKRWAN1310 boards we need to:

- Upgrade Firmware to ARD-078 1.2.3
- Record each board's DevEUI identifier
- Register all the boards with The Things Network
- Test that each board can make a LoRaWAN connection and transmit data

and optionally, if time permits, the following can also be done. Details will
not be covered here, but this will allow additional development to continue with
confidence.

- Install the 'paeiot-sensor-one' sketch
- Test data transmission with a connected sensor 

* Update the Firmware - MKRWANFWUpdate_standalone

** Requirements

- Laptop with Arduino Development Environment;
- Arduino MKRWAN Library (Not Version 2); and
- Arduino MKRWAN1310 board connected via USB Cable 

** Procedure
From the Library example code, load the 'MKRWANFWUpdate_standalone' sketch 
onto the MKRWAN1310 board to update the firmware.

Note: Once this sketch is loaded, it will reflash the firmware everytime the
MKRWAN1310 board is booted. It is best to upload another sketch as soon as
possible.

* Bring up - LoRaWAN - FirstConfiguration_AU915 (Step 1)

** Requirements
- Laptop with Arduino Development Environment;
- Arduino MKRWAN Library (Not Version 2);
- Arduino MKRWAN1310 board connected via USB Cable; and
- USB Stick or Shared Network Document (Google Doc)

** Procedure
1. Ensure that there is an antenna plugged into the MKRWAN1310.
2. Use the 'FirstConfiguration_AU915' sketch from the the 'paeiot-sensor-one'
   repository.

  If not available, it is possible to use the 'FirstConfiguration' sketch from
  the MKRWAN Arduino libray with some modificatins:

  - Change the 'modem.begin()' to use the AU915frequency plan, eg.
    'modem.begin(AU915)'.

  - Change the frequency channels in use by adding the following line, just
    before calling 'modem.setADR(true)';
 
    modem.sendMask("ff000000f000ffff00020000");

3. Install and run the sketch and record the Device EUI so that the device can
   be registered with "The Things Network".

   Store the DevEUI so that is can be accessed in the next two steps (eg. on a
   USB Stick or a shared network document).

   eg. mc-1  a8610a3334236c14f

* Register the Device with The Things Network

** Requirements

- Login the The Things Network, with administration privileges on the
  'enfieldlibrary-trial-v3' application
- *AppEUI* and *AppKey* details for the PAEIoT The Things Network Application
- *DevEUI* details from the previous step

** Procedure

Login to The Things Network, go to the 'enfieldlibrary-trial-v3' applications.

Register the device. The MKRWAN1310 board has been pre-registered with The Thing
Network for the Australian LoRaWAN Frequency plan for almost all of the required
settings (see step 3. below).

Login -> Applications -> Register end Device
  1. Brand: Arduino SA
     Model: Arduino MKR WAN 1310 
     Hardware Version: 1.0
     Firmware Version: 1.2.3
     Profile (Region): AU_915_928

  2. Enter registration data
     Frequency Plan: Australia 915-928 MHx, FSB 2 (used by TTN)
     AppEUI (copy from Application EUI)
     DevEUI (copy from recorded value)
     AppKey (copy from Application EUI)
     End device ID: mc-* (depending on device number, mc-1, mc-2 etc.)

Then

  3. Change LoRaWAN Regional Parameters version
     End Devices -> mc-* -> General settings
     Network layer
     Regional Parameters version: RP001 Regional Parameters 1.0.2 revision B 
     Save Settings

* Bring up - LoRaWAN - FirstConfiguration_AU915 (Step 2)

** Requirements

- Laptop with Arduino Development Environment;
- Arduino MKRWAN Library (Not Version 2);
- Arduino MKRWAN1310 board connected via USB Cable; and
- AppEUI and AppKey details for the PAEIoT The Things Network Application

** Procedure

1. Ensure that there is an antenna plugged into the MKRWAN1310.
2. Confirm that that you have the AppEUI and AppKey details
3. With the Serial monitor active on the Arduino Developent Tool

   - Select connection method: 1 (OTAA)
   - Enter your APP EUI
   - Enter your APP KEY

The MKRWAN 1310 should then try to connect with the LoRaWAN network. If
successful you will see the following message:

  Message sent correctly!

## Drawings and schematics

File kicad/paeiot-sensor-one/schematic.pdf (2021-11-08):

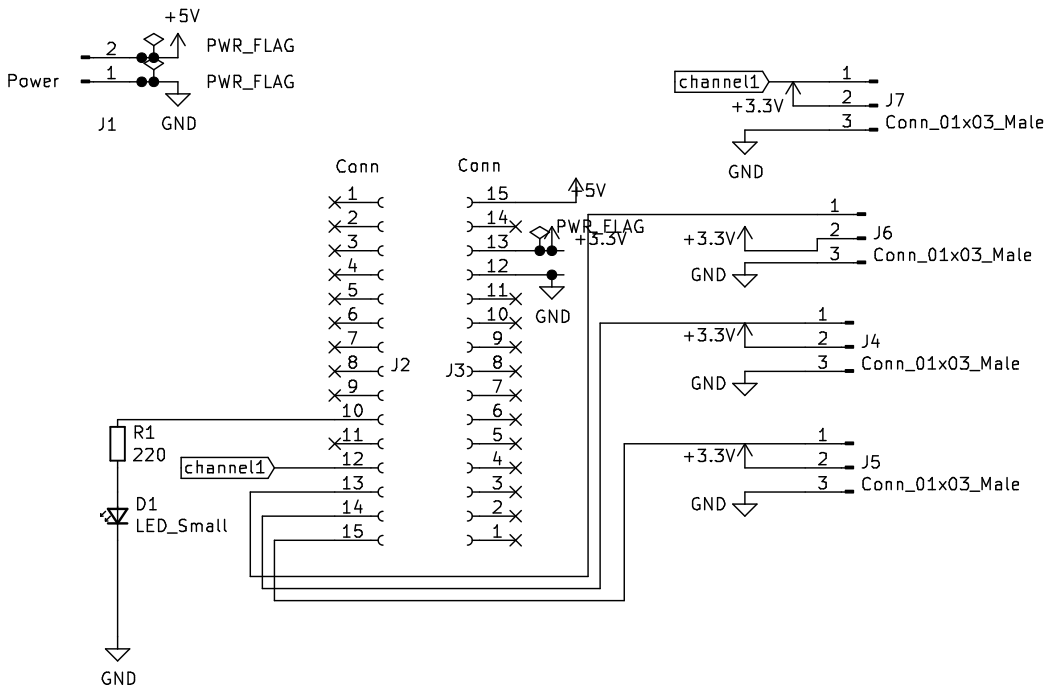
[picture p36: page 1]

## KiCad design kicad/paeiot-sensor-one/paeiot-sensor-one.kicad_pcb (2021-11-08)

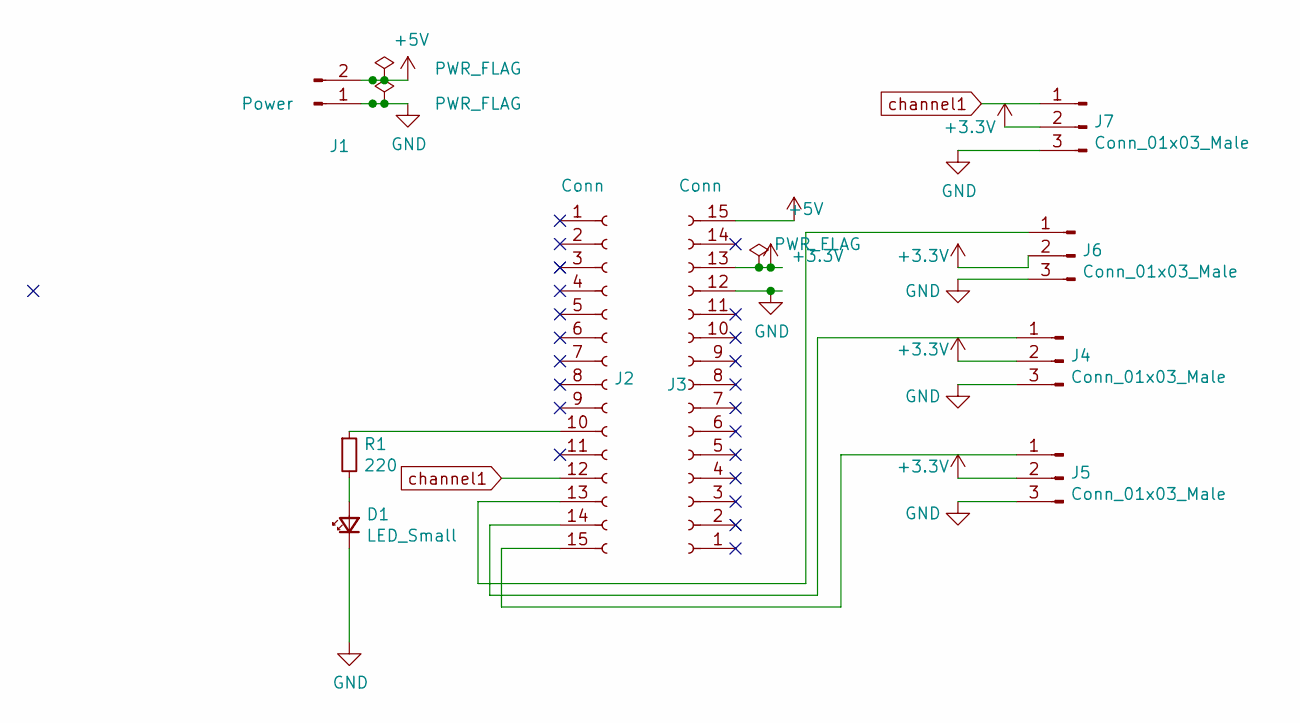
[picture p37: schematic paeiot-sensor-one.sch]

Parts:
D1: LED_Small; LED_D3.0mm
J1: Power; PinHeader_1x02_P2.54mm_Horizontal
J2, J3: Conn; PinHeader_1x15_P2.54mm_Vertical
J4, J5, J6, J7: Conn_01x03_Male; PinHeader_1x03_P2.54mm_Horizontal
R1: 220; R_Axial_DIN0309_L9.0mm_D3.2mm_P2.54mm_Vertical

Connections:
+3V3: J3.13, J4.2, J5.2, J6.2, J7.2
+5V: J1.2, J3.15
GND: D1.1 (K), J1.1, J3.12, J4.3, J5.3, J6.3, J7.3
unnamed: D1.2 (A), R1.2
unnamed: J2.10, R1.1
unnamed: J2.13, J6.1
unnamed: J2.14, J4.1
unnamed: J2.15, J5.1
channel1: J2.12, J7.1

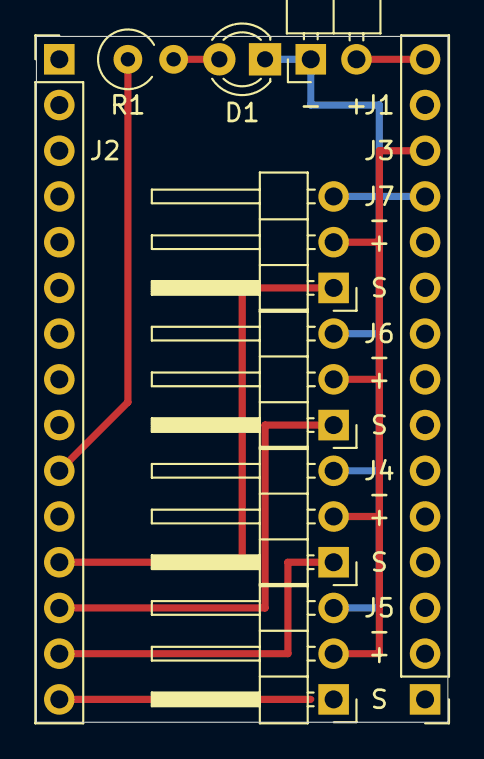
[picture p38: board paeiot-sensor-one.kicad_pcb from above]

Board: 2 copper layers, 22.9 x 38.1 mm, 9 parts (0 on the bottom side), 9 nets.

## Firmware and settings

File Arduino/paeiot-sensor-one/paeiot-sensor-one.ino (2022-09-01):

#include "arduino_secrets.h"
// -*- c -*-
/*
  PAE IoT LoRaWAN Sensor Module
  pariot-sensor-one

  Paul Schulz <paul@mawsonlakes.org>

  License: GNU Public License v3.0
*/

#define BUILD "v1.4.1      01 Sep 2022                                 "

#define TRUE 1
#define FALSE 0

// Capabilities
#define FEATURE_SERIAL TRUE
#define LORAWAN        TRUE
#define SENSOR_STATUS  TRUE
#define SENSOR_DHT     FALSE
#define SENSOR_CCS811  FALSE
#define SENSOR_BME280  FALSE
#define SENSOR_SCD30   TRUE

#define FEATURE_RTC           FALSE
#define FEATURE_WATCHDOG      TRUE
#define FEATURE_POWER_MONITOR TRUE

#include <Wire.h>
//////////////////////////////////////////////////////////////////////////////
// MKRWAN Library
// LoRaWAN code is based on mkrwan1310-example
#include <MKRWAN.h>
LoRaModem modem;

// Please enter your sensitive data in the Secret tab or arduino_secrets.h
String appEui = SECRET_APP_EUI;
String appKey = SECRET_APP_KEY;

//////////////////////////////////////////////////////////////////////////////
// CayenneLPP Library
// Low Power Payload format
#include<CayenneLPP.h>
CayenneLPP lpp(51);

//////////////////////////////////////////////////////////////////////////////
// Status
// Global Loop Delay (when not using Watchdog.sleep)
#define DELAY             60000  // 1m

uint32_t delayMS = DELAY;

void status_setup() {
  
}

void status_loop() {

}

//////////////////////////////////////////////////////////////////////////////
// DHT Sensor code is based on sensor-am2302-example
#include <Adafruit_Sensor.h>
#if SENSOR_DHT
#include <DHT.h>
#include <DHT_U.h>

// Four Temperature/Humidity sensors are supported
#define DHTPIN1 2 // Digital pin connected to the DHT sensor 1
#define DHTPIN2 3 // Digital pin connected to the DHT sensor 2
#define DHTPIN3 4 // Digital pin connected to the DHT sensor 3
#define DHTPIN4 5 // Digital pin connected to the DHT sensor 4

// CayenneLPP Channels
int dht_id1 = 0;
int dht_id2 = 1;
int dht_id3 = 2;
int dht_id4 = 3;

//#define DHT_NUMBER_SENSORS 4
//int dht_sensor_pins[DHT_NUMBER_SENSORS] = {2,3,4,5};
//int dht_sensor_ids[DHT_NUMBER_SENSORS]  = {0,1,2,3};

#define NOT_A_TEMPERATURE -99.9
#define NOT_A_HUMIDITY    -1.0
#define DELAY             60000
// Type of sensor in use:
//   DHT22 (AM2302)
#define DHTTYPE    DHT22

// Declare sensors
DHT_Unified dht1(DHTPIN1, DHTTYPE);
DHT_Unified dht2(DHTPIN2, DHTTYPE);
DHT_Unified dht3(DHTPIN3, DHTTYPE);
DHT_Unified dht4(DHTPIN4, DHTTYPE);

uint32_t minDelayMS;

void dht_setup() {
  dht1.begin();
  dht2.begin();
  dht3.begin();
  dht4.begin();

  // Print sensor details
  sensor_t sensor;
  Serial.println(F("------------------------------------------------------------------------------"));
  Serial.println(F("DHTxx Unified Sensors - Temperature and Humidity"));
  Serial.print(F("  Sensor 1: "));
  dht1.temperature().getSensor(&sensor);
  Serial.println(sensor.name);
    
  Serial.print(F("  Sensor 2: "));
  dht2.temperature().getSensor(&sensor);
  Serial.println(sensor.name);
    
  Serial.print(F("  Sensor 3: "));
  dht3.temperature().getSensor(&sensor);
  Serial.println(sensor.name);
    
  Serial.print(F("  Sensor 4: "));
  dht4.temperature().getSensor(&sensor);
  Serial.println(sensor.name);
}

void dht_loop() {
  // DHT Sensors
  // Get sensor data
  float t1,t2,t3,t4;
  float h1,h2,h3,h4;
  sensors_event_t event;

  // Sensor1
  dht1.temperature().getEvent(&event);
  if (isnan(event.temperature)) {
    t1 = NOT_A_TEMPERATURE;
  } else {
    t1 = event.temperature;
    lpp.addTemperature(dht_id1, t1);
  }

  dht1.humidity().getEvent(&event);
  if (isnan(event.relative_humidity)) {
    h1 = NOT_A_HUMIDITY;
  } else {
    h1 = event.relative_humidity;
    lpp.addRelativeHumidity(dht_id1, h1);
  }

  // Sensor 2
  dht2.temperature().getEvent(&event);
  if (isnan(event.temperature)) {
    t2 = NOT_A_TEMPERATURE;
  } else {
    t2 = event.temperature;
    lpp.addTemperature(dht_id2, t2);
  }

  dht2.humidity().getEvent(&event);
  if (isnan(event.relative_humidity)) {
    h2 = NOT_A_HUMIDITY;
  } else {
    h2 = event.relative_humidity;
    lpp.addRelativeHumidity(dht_id2, h2);
  }

  // Sensor 3
  dht3.temperature().getEvent(&event);
  if (isnan(event.temperature)) {
    t3 = NOT_A_TEMPERATURE;
  } else {
    t3 = event.temperature;
    lpp.addTemperature(dht_id3, t3);
  }

  dht3.humidity().getEvent(&event);
  if (isnan(event.relative_humidity)) {
    h3 = NOT_A_HUMIDITY;
  } else {
    h3 = event.relative_humidity;
    lpp.addRelativeHumidity(dht_id3, h3);
  }

  // Sensor 4
  dht4.temperature().getEvent(&event);
  if (isnan(event.temperature)) {
    t4 = NOT_A_TEMPERATURE;
  } else {
    t4 = event.temperature;
    lpp.addTemperature(dht_id4, t4);
  }

  dht4.humidity().getEvent(&event);
  if (isnan(event.relative_humidity)) {
    h4 = NOT_A_HUMIDITY;
  } else {
    h4 = event.relative_humidity;
     lpp.addRelativeHumidity(dht_id4, h4);
  }
}

#endif // SENSOR_DHT

////////////////////////////////////////////////////////////////////////////// 
// Sensor CCS811 - C02 and Volatile Organic Compounds
// Uses Adafruit_CCS811 Library
// CCS811 Sensor code based on CCS811_test example
// Uses I2C Interface
#if SENSOR_CCS811

# include "Adafruit_CCS811.h"
Adafruit_CCS811 ccs;

int ccs811_id1 = 16;
int ccs811_id2 = 17;
int ccs811_present=0;

void ccs811_setup() {
  Serial.println(F("------------------------------------------------------------------------------"));
  Serial.println(F("CCS811 - C02 and Volatile Organic Compounds"));
  Serial.print(F("  CayenneLPP Id CO2:  "));
  Serial.println(ccs811_id1);
  Serial.print(F("  CayenneLPP Id TVOC: "));
  Serial.println(ccs811_id2);

  if(ccs.begin()) {
    Serial.print("  Detected");
    ccs811_present=1;
  } else {
    Serial.println("Failed to detect sensor!");
  }
  
  // Wait for the sensor to be read.
  if (ccs811_present) {
    while(!ccs.available());
    Serial.println(" - Ready");
  }
}

void ccs811_loop() {
  if(ccs811_present) {
    if(ccs.available()){
      if(!ccs.readData()){
        lpp.addPower(ccs811_id1, ccs.geteCO2());
        lpp.addPower(ccs811_id2, ccs.getTVOC());        
      } else {
        Serial.println("ERROR!");
      }
    }
  } else {
    // Send Test Data
    lpp.addPower(ccs811_id1, 432);
    lpp.addPower(ccs811_id2, 234);
  }
}

#endif // SENSOR_CCS811
                                                  
////////////////////////////////////////////////////////////////////////////// 
// SparkFun BME280 - Version: Latest 
#if SENSOR_BME280

#include <SparkFunBME280.h>
#define BME280_ADDR 0x76
BME280 myBME280;

int bme280_id = 20;
int bme280_present = 0;

void bme280_setup() {
  Serial.println(F("------------------------------------------------------------------------------"));
  Serial.println("BME280 -Temperature, Pressure and Humidity");
  //For I2C, enable the following and disable the SPI section
  myBME280.settings.commInterface = I2C_MODE;
  myBME280.settings.I2CAddress = 0x76; //BME280_ADDR
  delay(10);
  //Initialize BME280
  myBME280.settings.runMode = 3; //Normal mode
  myBME280.settings.tStandby = 0;
  myBME280.settings.filter = 4;
  myBME280.settings.tempOverSample = 5;
  myBME280.settings.pressOverSample = 5;
  myBME280.settings.humidOverSample = 5;
  delay(10); 
  myBME280.begin();
}

void bme280_loop() {
  //Returns temperature
  Serial.print("[");
  Serial.print(myBME280.readTempC(), 2);
  Serial.print(" C]");
  //Returns pressure
  Serial.print("[");
  Serial.print(myBME280.readFloatPressure()/100.0, 2);
  Serial.print(" hPa]");
  Serial.print("[");
  Serial.print(myBME280.readFloatHumidity(), 0);
  Serial.print(" %RH]");
}

#endif // SENSOR_BME280

////////////////////////////////////////////////////////////////////////////// 
// Sensor SCD30 - C02, Temperatue and Humidity
#if SENSOR_SCD30
#include <Adafruit_SCD30.h>

Adafruit_SCD30  scd30;

int scd30_id=10;
int scd30_present=0;

void scd30_setup() {
  Serial.println(F("------------------------------------------------------------------------------"));
  Serial.println(F("SCD30 - CO2, Temperature and Humidity Sensor"));
  Serial.print(F("  CayenneLPP Id: "));
  Serial.println(scd30_id);

  // Try to initialize!
  if (scd30.begin()) { 
    Serial.println("  SCD30 Found!");
    scd30_present=1;
  } else {
    Serial.println("  Failed to find SCD30 chip");
  }
}

void scd30_loop() {
  //Serial.println("Reading SCD30 sensor data");

  if(scd30_present){
    if (scd30.dataReady()){
      if (!scd30.read()){
        Serial.println("Error reading SCD30 sensor data");
        return;
      }

      lpp.addTemperature(scd30_id, scd30.temperature);
      lpp.addRelativeHumidity(scd30_id, scd30.relative_humidity);
      lpp.addPower(scd30_id, scd30.CO2);
      // Concetration is not yet supported in NodeRed 
      //lpp.addConcentration(scd30_id, scd30.CO2);
    }
  } else {
    // Test Data
    lpp.addTemperature(scd30_id, 0.0);
    lpp.addRelativeHumidity(scd30_id, 0.0);
    lpp.addPower(scd30_id, 0);
    //lpp.addConcentration(scd30_id, 880);

  }
}

#endif // SENSOR_SCD30

//////////////////////////////////////////////////////////////////////////////
// Real Time Clock (RTC)
#if FEATURE_RTC

void rtc_setup() {
  // set alarm date in the future to test
  rtc.setAlarmMonth(12);
  rtc.setAlarmYear(2022);
  set_next_alarm(1);
  rtc.attachInterrupt(alarmMatch);
  rtc.enableAlarm(rtc.MATCH_HHMMSS);
  Serial.println(F("----------------------------------------------------------------------------"));
  print_rtc();
  Serial.println(F("----------------------------------------------------------------------------"));
}

void rtc_loop() {
  if(rtc_matched) { // FEATURE_RTC interupt was fired
    rtc_matched=0;
    set_next_alarm(0);
    print_rtc();
  }
}

#endif //FEATURE_RTC

////////////////////////////////////////////////////////////////////////////// 
// Watchdog
// https://github.com/adafruit/Adafruit_SleepyDog
#if FEATURE_WATCHDOG
#include <Adafruit_SleepyDog.h>
#define FEATURE_WATCHDOG_TEST FALSE

int watchdog_timer=30000; // 30 second watchdog

void watchdog_setup() {
  Serial.println(F("----------------------------------------------------------------------------"));
  Serial.println(F("Watchdog"));
  Serial.print(F("  Timer: "));
  Serial.print(watchdog_timer/1000);
  Serial.println(F("s"));
  //Publish reason for restart (power, FEATURE_WATCHDOG etc)
  Serial.print("  Reset Reason code: ");  
  Serial.println(PM->RCAUSE.reg);

  Watchdog.enable(watchdog_timer);
}

void watchdog_loop() {
  Watchdog.reset();  // Kick watchdog
  Watchdog.sleep();  // Low power sleep
  Serial.print(".");

  #if FEATURE_WATCHDOG_TEST
  // trip the watchdog after 2 succesful loops
  if (millis() > 2*rtc_delay*60*1000) {
    delay(30*1000);  // this is longer than the watchdog trigger
  };
  #endif
}

#endif

////////////////////////////////////////////////////////////////////////////// 
// Power Monitor
#if FEATURE_POWER_MONITOR

int powermon_panel_pin   = A0;
int powermon_battery_pin = A1;
int powermon_enable_pin  = 0;
int a2d_resolution       = 10;  // 10 bits
int powermon_max_reading = (1<<a2d_resolution) - 1; 
// It is possible to change the resolution if needed

void powermon_setup() {
  Serial.println(F("----------------------------------------------------------------------------"));
  Serial.println(F("Power Monitor (for Microclimates Sensor)"));
  Serial.println(F("  Voltage 1: Panel Voltage"));
  Serial.println(F("  Voltage 2: Battery Voltage"));
  Serial.print(F("  Resolution bits: "));
  Serial.println(a2d_resolution);
  Serial.print(F("  Maximum Count: "));
  Serial.println(powermon_max_reading);

  // Enable control for battery voltage reading, and disable.
  pinMode(powermon_enable_pin, OUTPUT);
  digitalWrite(powermon_enable_pin, LOW);

  // Change Resolution
  analogReadResolution(a2d_resolution); 
}

void powermon_loop() {
  int panel_reading   = 0;
  int battery_reading = 0;
  int max_reading = powermon_max_reading;
  float ref_voltage = 3.3;

  float panel_voltage;   // 0.0 - 22.0 V
  float battery_voltage; // 0.0 - 7.2 V 

  digitalWrite(powermon_enable_pin, HIGH);
  delay(100);
  panel_reading = analogRead(powermon_panel_pin);
  battery_reading = analogRead(powermon_battery_pin);
  digitalWrite(powermon_enable_pin, LOW);

  panel_voltage = 1.0*panel_reading/max_reading*ref_voltage*1047/47;
  battery_voltage = 1.0*battery_reading/max_reading*ref_voltage*1150/150;

  lpp.addVoltage(0, panel_voltage); 
  lpp.addVoltage(1, battery_voltage); 
}

#endif // FEATURE_POWER_MONITOR

////////////////////////////////////////////////////////////////////////////// 
// Utility Functions


//////////////////////////////////////////////////////////////////////////////
// Setup

void setup() {
  // Initialize digital pin LED_BUILTIN as an output.
  pinMode(LED_BUILTIN, OUTPUT);
  digitalWrite(LED_BUILTIN, HIGH);
   
  Serial.begin(115200);
  Serial.println("-");
  
  digitalWrite(LED_BUILTIN, HIGH);
  delay(8000); // Allow serial monitor to catch up.
  digitalWrite(LED_BUILTIN, LOW);

  Serial.println(F("------------------------------------------------------------------------------"));
  Serial.println(F("---    __  __ _                _ _            _                            ---"));    
  Serial.println(F("---   |  \\/  (_)__ _ _ ___  __| (_)_ __  __ _| |_ ___ ___                  ---"));
  Serial.println(F("---   | |\\/| | / _| '_/ _ \\/ _| | | '  \\/ _` |  _/ -_|_-<                  ---"));
  Serial.println(F("---   |_|  |_|_\\__|_| \\___/\\__|_|_|_|_|_\\__,_|\\__\\___/__/                  ---"));                     
  Serial.println(F("---                                                                        ---"));
  Serial.println(F("---   Sensor One                                                           ---"));  
  Serial.print("---   Build: ");
  Serial.print(BUILD);
  Serial.println(F("      ---"));
  Serial.println(F("---   PAE IoT Experimenters                                                ---"));
  Serial.println(F("---   https://stemlibrary.space/iot-experimenters                          ---"));
  Serial.println(F("------------------------------------------------------------------------------"));
  
  // Setup LoRaWAN Modem
  Serial.println("LoRaWAN - Radio");
  Serial.println("  Modem: Australian Band Plan AU915 ");
  // change this to your regional band (eg. US915, AS923, ...)
  if (!modem.begin(AU915)) {
    Serial.println("  Failed to start module");
    while (1) {}
  };
  modem.sendMask("ff000000f000ffff00020000");
  Serial.print("  Module version is: ");
  Serial.println(modem.version());
  Serial.print("  DevEUI is: ");
  Serial.println(modem.deviceEUI());
  Serial.print("  AppEUI is: ");
  Serial.println(SECRET_APP_EUI);
  Serial.print("  AppKey is: ");
  Serial.println(SECRET_APP_KEY);
    
  int connected = modem.joinOTAA(appEui, appKey);

  if (!connected) {
    Serial.println("Something went wrong; are you indoor? Move near a window and retry");
      while (1) {}
    }

  // Set poll interval to 60 secs.
  modem.minPollInterval(60);

  // Setup Sensors
  #if SENSOR_DHT
  dht_setup();
  #endif  

  #if SENSOR_CCS811
  ccs811_setup();
  #endif // SENSOR_CCS811
  
  #if SENSOR_BME280
  bme280_setup();
  #endif // SENSOR_BME280

  #if SENSOR_SCD30
  scd30_setup();
  #endif // SENSOR_SCD30

  #if FEATURE_WATCHDOG
  watchdog_setup();
  #endif

  #if FEATURE_POWER_MONITOR
  powermon_setup();
  #endif

  Serial.println(F("------------------------------------------------------------------------------"));
  Serial.println(F("Features"));
  Serial.println(F("  CayenneLPP "));
  Serial.print  (F("  Transmit Delay:  2m40s (approx.)\n"));
  Serial.println(F("------------------------------------------------------------------------------"));
  
} // End of setup

//////////////////////////////////////////////////////////////////////////////
void loop() {

  // Reset LPP Packet
  lpp.reset();
 
  #if SENSOR_DHT
  dht_loop();
  #endif // SENSOR_DHT

  #if SENSOR_CCS811
  ccs811_loop();
  #endif // SENSOR_CCS811

  #if SENSOR_BME280
  bme280_loop();
  #endif // SENSOR_BME280 

  #if SENSOR_SCD30
  scd30_loop();
  #endif // SENSOR_SCD30

  #if FEATURE_POWER_MONITOR
  powermon_loop();
  #endif //FEATURE_POWER_MONITOR

  // Begin Transmit
  digitalWrite(LED_BUILTIN, HIGH);

  int err;
  modem.beginPacket();
  modem.write(lpp.getBuffer(),lpp.getSize());

  err = modem.endPacket(true);
  if (err > 0) {
    Serial.print("  [tx]");
  } else {
    Serial.print(" [error]");
  }

  delay(1000);

  if (modem.available()) {
    Serial.println(" [rx]");

    char rcv[64];
    unsigned int i = 0;
    while (modem.available()) {
      rcv[i++] = (char)modem.read();
    }

    Serial.print(" Received: ");
    for (unsigned int j = 0; j < i; j++) {
      Serial.print(rcv[j] >> 4, HEX);
      Serial.print(rcv[j] & 0xF, HEX);
      Serial.print(" ");
    }
  }

  digitalWrite(LED_BUILTIN, LOW);

  Serial.print(" [sleep]\n");

  for(int i=0; i<10; i++){
    #if FEATURE_WATCHDOG
    watchdog_loop();   // Kick watchdog and sleep.
    #else
    delay(delayMS/10); // Sleep
    #endif

  }
}

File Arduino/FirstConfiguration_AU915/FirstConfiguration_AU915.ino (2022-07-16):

/*
  First Configuration
  This sketch demonstrates the usage of MKR WAN 1300/1310 LoRa module.
  This example code is in the public domain.

  Modified to support the AU915 (Australian) Band Plan.
*/

#include <MKRWAN.h>

LoRaModem modem;

// Uncomment if using the Murata chip as a module
// LoRaModem modem(Serial1);

String appEui;
String appKey;
String devAddr;
String nwkSKey;
String appSKey;

void setup() {
  // put your setup code here, to run once:
  Serial.begin(9600);
  while (!Serial);
  Serial.println("Welcome to MKR WAN 1300/1310 first configuration sketch");
  Serial.println("Register to your favourite LoRa network and we are ready to go!");
  // change this to your regional band (eg. US915, AS923, ...)
  if (!modem.begin(AU915)) {
    Serial.println("Failed to start module");
    while (1) {}
  };
  Serial.print("Your module version is: ");
  Serial.println(modem.version());
  if (modem.version() != ARDUINO_FW_VERSION) {
    Serial.println("Please make sure that the latest modem firmware is installed.");
    Serial.println("To update the firmware upload the 'MKRWANFWUpdate_standalone.ino' sketch.");
  }
  Serial.print("Your device EUI is: ");
  Serial.println(modem.deviceEUI());

  // Enable AU915-928 channels
  // LoRaWAN® Regional Parameters and TTN specification: channels 8 to 15 plus 65 
  modem.sendMask("ff000000f000ffff00020000");
  Serial.println(modem.getChannelMask());
  modem.setADR(true);
  //join();
  
  int mode = 0;
  while (mode != 1 && mode != 2) {
    Serial.println("Are you connecting via OTAA (1) or ABP (2)?");
    while (!Serial.available());
    mode = Serial.readStringUntil('\n').toInt();
  }

  int connected;
  if (mode == 1) {
    Serial.println("Enter your APP EUI");
    while (!Serial.available());
    appEui = Serial.readStringUntil('\n');

    Serial.println("Enter your APP KEY");
    while (!Serial.available());
    appKey = Serial.readStringUntil('\n');

    appKey.trim();
    appEui.trim();

    connected = modem.joinOTAA(appEui, appKey);
  } else if (mode == 2) {

    Serial.println("Enter your Device Address");
    while (!Serial.available());
    devAddr = Serial.readStringUntil('\n');

    Serial.println("Enter your NWS KEY");
    while (!Serial.available());
    nwkSKey = Serial.readStringUntil('\n');

    Serial.println("Enter your APP SKEY");
    while (!Serial.available());
    appSKey = Serial.readStringUntil('\n');

    devAddr.trim();
    nwkSKey.trim();
    appSKey.trim();

    connected = modem.joinABP(devAddr, nwkSKey, appSKey);
  }

  if (!connected) {
    Serial.println("Something went wrong; are you indoor? Move near a window and retry");
    while (1) {}
  }

  delay(5000);

  int err;
  modem.setPort(3);
  modem.beginPacket();
  modem.print("HeLoRA world!");
  err = modem.endPacket(true);
  if (err > 0) {
    Serial.println("Message sent correctly!");
  } else {
    Serial.println("Error sending message :(");
  }
}

void loop() {
  while (modem.available()) {
    Serial.write(modem.read());
  }
  modem.poll();
}

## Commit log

2021-08-05 arduino: Rename sketch directory
2021-08-05 arduino: Adds .gitignore to remove arduino_secrets.h from commits
2021-08-05 Arduino: Removed .gitignore
2021-08-05 stl: Adds baseplate STL files
    [paeiot-sensor-one-baseplate.stl]
2021-08-05 stl: Fixes Typo
2021-08-05 stl: Adds link to TinkerCAD
2021-08-12 stl: Updates after first round of 3D printing
    - Added hole for MKRWAN1310 pins.
    - Added baseplate mounting holes M4 (assumed).
    - Added cutout for glands.
    [paeiot-sensor-one-baseplate.stl]
2021-08-14 stl: Move/fix corner cutout on base plate
    [paeiot-sensor-one-baseplate.stl]
2021-08-14 fritzing: Adds initial wirign diagram
    [paeiot-sensor-one.fzz]
2021-08-14 fritzing: Fixes circuit and board routing
    [paeiot-sensor-one.fzz]
2021-08-30 fritzing: Created v1.0 of the printed circuit board
    Supports two temperature/humidity sensors.
    [paeiot-sensor-one.fzz]
2021-09-21 friting: (Minor) Finessing the board layout
    [paeiot-sensor-one.fzz]
2021-09-21 fritzing: (minor) Fix PCB screen (remove extra label)
    [paeiot-sensor-one.fzz]
2021-10-02 fritzing: Fixes issues with PCB board
    - Uses new Fritzing template file (for MKRWAN1300) as previous ones
    did not have a correct PCB template.
    Downloaded from: https://forum.fritzing.org/t/arduino-mkr-wan-1300/6317/8
    [paeiot-sensor-one.fzz]
2021-10-02 Arduino: Removes serial initialisation check, which halts reset
    The original code checked to see whether the USB serial connected during
    initialisation process. This is a problem when the sensor need to reboot and it
    is not connected to anything.
    [paeiot-sensor-one.ino]
2021-10-09 doc: Added bill-of-materials
    [paeiot-sensor-one.fzz]
2021-10-09 Arduino:(minor) Fixes code ater merge
    [paeiot-sensor-one-shield-base.stl]
2021-10-09 friting:minor Adds fritzing file back in
    [paeiot-sensor-one.fzz]
2021-10-29 arduino: Expands number of sensor channels to 4
    Version 1.2
    Lots of fixes and changes
    - 4 channels for temperature/humidity sensors
    - Improved serial status output
    - Status LED flashes when transmitting
    - Code added for formatting/processing data
    [paeiot-sensor-one.ino]
2021-10-29 blog: Updates to status report
    [paeiot-sensor-one-baseplate-10.stl, paeiot-sensor-one-baseplate-7.stl]
2021-11-08 kicad: Adds initial schematic and board layout in KiCAD
    [paeiot-sensor-one.csv, paeiot-sensor-one.kicad_pcb, paeiot-sensor-one.sch]
2022-01-19 blog: Quick status report on Indoor Enclosure sub-project
2022-01-20 README: Update with newer image of inside enclosure
2022-03-22 blog: Added sensor update
2022-07-16 Arduino: Added AU915 version of FirstConfiguration script
    Modifications have been made to the MKRWAN1310 to work with the public
    Australian LoRaWAN network.
2022-07-16 Arduino: Add MKRWANFWUpdate_standalone sketch - ARD-078 1.2.3
    Add the sketch from MKRWAN library examples for revision control. Compile and
    install and run this sketch to upgrade the MKRWAN1310 LoRa Firmware to the
    version:
    ARD-078 1.2.3
    This sketch will run and reinstall the firmware whenever the MKRWAN1310 board is
    powered on, so replace with another sketch once firmware upgrade has been done.
    [MKRWANFWUpdate_standalone.ino]
2022-07-16 Arduino: WIP v1.3.1 - Updates to paeiot-sensor-one
    - Added Watchdog code.
    - Started refactoring code into separate 'setup' and 'loop' sections for
    different sensors and features.
2022-07-18 Arduino: WIP v1.3.3rc1 - Added Power Monitoring code
    Also, refactored the original DHT code into 'setup' and 'loop' functions.
    Dummy temperature and humidity reading are being sent.
2022-07-19 Arduino: WIP v1.2.2pre1 - Refactoring sensor code
    Putting code for various sensors into their own _setup and _loop functions.
2022-07-21 Arduino: WIP v1.3.3pre2 - Detecting and sending DHT sensor data
2022-07-23 Arduino: WIP v1.3.3pre2 - Bump version to test compile
2022-07-23 Arduino: WIP v1.3.4pre2 Refactor to remove dependency on DHT code
2022-07-26 Arduino: WIP v1.3.4pre3 - Fix AD voltage calculation
    Added some debugging code that can be removed later. Just sends raw AD counts
    for verification.
    Added code so that the A2D resolution can be adjusted (higher) if
    required.
    [paeiot-sensor-one.ino]
2022-07-27 Arduino: WIP v1.3.4pre4 - Adjust test data values for SCD30
    If the SCD30 sensor hardware is not detected when the SCD30 feature is enabled,
    the unit will transmit test data instead.
    To make it more obvious that this is test data (other than it not changing over
    time) to values have been chosen to be:
    Temperature = 0.0 degC
    Relative Humidity = 0.0 %
    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
2022-07-31 Arduino: v1.4.0pre1 - Minor fixes
    Feature complete for data acquisition.
    [paeiot-sensor-one.ino]
2022-09-01 v1.4.1: Change delay to use low power sleep
    Reprogramming won't work when in sleep mode (getting errors) but there is
    sufficient delay on boot to allow USB loader to take control. So, hit reset on
    the board before hitting the 'compile and program' button on the Arduino IDE.
    [paeiot-sensor-one.ino]
2022-10-17 doc: Add Arduino Sketch design description documentation
